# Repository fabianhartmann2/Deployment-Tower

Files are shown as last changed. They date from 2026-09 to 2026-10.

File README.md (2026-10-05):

# Integrated Deployment Station CAD

Parametric CadQuery concept for an FDM-printed station containing a Mac mini M4, a Teltonika RUTM30, and a Mean Well APV-35-36. The modeled default is a **165 x 165 x 280 mm fixed enclosure** (base, panels, and cap included; removable handle and antennas excluded), with a **1:1:1.697** width:depth:height ratio.

> **Prototype status and safety boundary:** this package is editable concept/prototype mechanical CAD. It is not a production release, an electrical design, a safe-working-load rating, or evidence of regulatory compliance. Computational PASS results prove only the checks named in the generated report. Actual hardware fit, cables and overmoulds, printing tolerances, thermal behavior, carrying load/cycles, and qualified 230 V electrical review and tests are still pending. Do not energize a built unit until a competent electrical designer has completed the architecture and a qualified person has inspected and tested the complete assembly.

## Architecture

The stack from bottom to top is:

1. a removable dark base with 5 mm feet, a 116 mm intake opening, and a continuous lower-rear Mac-button path;
2. a horizontal Mac mini on a physically calibrated Ø112 open-ring, three-pad cradle with 0.30 mm side clearance, four lowered positive-Z clip/cam retainers, and two bottom-operated release rails;
3. a shell-supported, separately covered APV/mains compartment, a distinct low-voltage/data lane, and a provisional reserved Mac-AC route;
4. a horizontal RUTM30 on four replaceable compliant support pads and a shell-supported removable tray at `Z=151`, retained at the rear corners by two adjustable M3-screwed stops rather than brittle flexure clips; and
5. a reinforced upper shell and laterally sliding cap with a removable handle fastened from the cap underside by four hidden M3 screws, broad feet, full-depth handle inserts, two selected dovetail rails, and shell-tied load paths.

The lower and upper shell modules fit the Bambu Lab X1 Carbon's 256 mm build cube. Their load-bearing split uses six hidden M4 joints, an internal U-shaped belt in each shell, and three locating keys; all screw heads, tool corridors, and insert openings remain inside the closed exterior skin. A physical v3 assembly found the original Ø7.6 head pockets tight for measured Ø7.0 heads, so the current source uses Ø8.2 pockets plus 8.4 mm internal-only entry slots. The formerly unsupported 4 mm rear sill is tied into the lower shell by an internal angle beam. The upper shell carries two recessed 70 x 70 mm logo panels using concealed 6 x 3 mm shell magnets opposed by 6 x 1.5 mm panel magnets. The former side antenna docks and their shell bosses are removed; four cellular and two Wi-Fi antennas now mount on six screw-clamped rear bulkheads. The C8 island and closed terminal tunnel move with the complete power compartment to +X; the full-height rear service panel removes around the island. Raised cable-tie bridges preserve a solid box floor, the two APV axes use top-service blind insert pilots, and four wall-tied bosses support the cover. These are mechanical provisions only and do not authorize wiring or energization.

The current joint labels deliberately distinguish **M3x14 base**, **M3x10 Mac-cradle**, hidden underside **M3x14 handle**, recessed low-head **M3x6 router-tray**, **M3x8 service/cover**, hidden **M4x10 cap locks**, and **M4x18 shell-seam** stacks. Physical coupons selected Ø4.2 M3 and Ø5.4 M4 insert pilots. The handle screws pass upward through the detached cap into the full 8 mm feet; the selected dovetails carry vertical cap load while two M4 locks prevent sideways motion. Exact screw heads, engagement, torque, pull-out, and final lengths remain provisional until joint-stack tests pass.

The official router geometry is imported from `reference/0112_RUTM30AMBKX_02.STEP`. The Mac, APV, antennas, C8, extensions, plugs, and cable paths are controlled placeholders; see [assumptions.md](reports/assumptions.md).

## Coordinate system

All dimensions are millimetres.

- Origin: centre of the external footprint on the desk-contact plane.
- +X: right when looking at the front.
- +Y: toward the rear service face.
- +Z: upward.
- Fixed body: approximately `X=-82.5..82.5`, `Y=-82.5..82.5`, `Z=0..280`.
- Equipment positions in `layout.py` are reference-envelope centres.

The principal centres are Mac `(0,-8,41)`, APV `(35,5,103.55)`, and RUTM30 `(0,28,170.5)`. The Mac reference preserves 50 mm overall height while representing the physically observed 8 mm underside drop below its retained square body. Full datums, packaging ranges, and parameter defaults are in [dimensions.md](reports/dimensions.md).

## Build, test, and export

Python 3.10-3.12 is supported; CadQuery is pinned to 2.6.1. From `cad/`:

```sh
python3 -m venv .venv
.venv/bin/python -m pip install --upgrade pip
.venv/bin/python -m pip install -e ".[test]"
.venv/bin/python -m pytest
.venv/bin/python -m deployment_station.export
```

On Windows, substitute `.venv\Scripts\python.exe` for `.venv/bin/python`. Installed console-script equivalents are `deployment-station-export`, `deployment-station-validate`, and the macOS-only `deployment-station-quicklook`.

The export command rebuilds all parts from `parameters.py`, writes STEP/STL and renders, reopens every STEP, validates every STL, writes the manifest and reports, and exits non-zero if any validation result is `FAIL`. A report-only rerun against the existing STL directory is:

```sh
.venv/bin/python -m deployment_station.validation
```

The complete export command is the authoritative check. The standalone report-only command reruns geometry and whole-file mesh checks; export additionally verifies the actual packed print orientation and independently checks every disconnected mesh component for grounding and manifold integrity.

The non-default proportional-scaling API intentionally raises `ValueError`. Absolute equipment, port, split, and load-path datums cannot be safely scaled as one ratio; a different enclosure width requires a coordinated repack and new verification.

## Computational-result authority

The source checks are fail-gated, but aggregate counts and artifact hashes are intentionally not frozen in this narrative before regeneration. Run the export command after every source change, then use [validation_results.md](reports/validation_results.md), `validation.json`, and `export_manifest.json` as the generated record for that exact build. The checks cover installed-part pairs, selected equipment/mount intersections, print-volume and solid validity, critical mating geometry, STEP reopen, and STL mesh integrity. A zero-FAIL report remains computational evidence only; every physical, thermal, load, signal, cable, and electrical item marked WARN or PENDING remains open.

## Generated outputs

The current source registry expects **18 printable definitions**: 14 installed assembly parts plus four reusable/non-installed templates. Regeneration writes:

- one printable-part STEP and one print-oriented STL for each registered definition;
- 21 coupon STEP files and 21 coupon STL files, including retained historical fit articles;
- `complete_assembly.step`, `exploded_assembly.step`, and `packaging_study.step`;
- `component_envelopes.step`, containing non-printable references and keep-outs;
- four deterministic PNG renders; and
- `reports/export_manifest.json`, with the authoritative regenerated paths, sizes, SHA-256 hashes, and design-space STEP bounding boxes.

STEP files remain in assembly coordinates. STL files receive the documented print-orientation transform and are placed on `Z=0`. No 3MF is generated because this export path cannot preserve dependable slicer/process settings.

### macOS Finder model

`exports/interactive/complete_assembly_finder.usdz` is a color, interactive Quick Look model containing all 14 installed printed parts plus equipment and interface-hardware references. Select it in Finder and press Space, or open it directly, to orbit, pan, and zoom. It uses metres-per-unit metadata corresponding to the millimetre CAD model and passes Apple's strict RealityKit USDZ validation.

On macOS with the Apple USD command-line tools available, regenerate it with:

```sh
.venv/bin/python -m deployment_station.quicklook
```

This convenience visualization is generated separately from the fail-gated STEP/STL manifest and is not a manufacturing export.

## Direct versus extended interfaces

| Interface | Decision | CAD implementation | Verification boundary |
| --- | --- | --- | --- |
| Four cellular SMA connections | Rear bulkhead extensions | Four of six Ø6.6 rear holes with thinned 2.0 mm clamping lands; row sequence Mobile / Wi-Fi / Mobile / Mobile / Wi-Fi / Mobile | Exact pigtails, nut torque, strain relief, first bends, and antenna load test pending |
| Two Wi-Fi RP-SMA connections | Rear bulkhead extensions | Two of the same six screw-clamped rear positions; former side docks removed | Exact RP-SMA gender, coax routing, antenna spacing, RF performance, and load test pending |
| External Ethernet | One replaceable extension | One accepted 17 x 14 opening with 27.6 mm mounting pitch directly in the rear panel | Exact screws/locking, latch access, bend space, strain support, and link performance pending |
| Internal Mac Ethernet | Internal patch lead | Placeholder plug volume in low-voltage lane | Consumes one native router port; actual lead fit pending |
| Mac HDMI | Replaceable extension | Accepted V7 mount relocated to `(-6,108)`—60 mm from the right and 90 mm from the bottom when viewed from behind—with a 13 mm shelf and two top-down blind M3 mounts | Cable bend, strain support, access, and functional test pending |
| Two Mac USB-C | Replaceable extensions | Accepted V7 mounts relocated to `(-24,68)` and `(-41,78)`—rear-view right/bottom offsets `(42,50)` and `(25,60)`—mounted from inside to 6 mm blind-boss bridges with sharp 14 x 6.5 x 2.5 mm reliefs | Cable bend, strain support, access, and functional test pending |
| Mac AC | Internal only | Diameter-12 gland and continuous stepped 6 mm reserved envelope from the covered zone toward the provisional Mac connector | This is packaging space, not a selected conduit or completed branch architecture; qualified design remains PENDING |
| Candidate measured C8 | Direct component | Accepted 21 x 12.5 opening on the fixed inlet island at `(38,116)` with two full-depth Ø4.2 M3 insert pockets, integral with the relocated closed compartment | Insert installation, shroud, wiring, and electrical review pending |
| Mac power button | Direct mechanical reach | Continuous rear-left/underside finger path; no Mac modification | Handedness corrected by full-cradle trial; physical ergonomics/guarding cycles pending |

The two native router ports now have a defined one-to-one allocation: one internal Mac link and one external Ethernet extension. No second external Ethernet opening is modeled.

## Source map

| Module | Responsibility |
| --- | --- |
| `parameters.py`, `layout.py` | Defaults, datums, and packaging locations |
| `components.py` | Official router import; controlled equipment, hardware, cable, and removal placeholders |
| `base.py`, `mac_mount.py` | Base, intake/button path, three 2 mm pad positions in 1 mm seats, four clip/cam retainers, two bottom release rails, and shell-fastened cradle ears |
| `shell.py` | Split shell, reinforced rear sill, three seam keys, six hidden internal seam joints/belts, magnetic logo receivers, dovetail cap rails, equipment supports, and handle load path |
| `router_tray.py`, `rear_panel.py` | Router support, physically corrected side/top fit, four compliant pads, adjustable screw-mounted rear stops, and a full-height one-piece rear panel with six direct RF bulkheads and the measured extension mounts |
| `power_compartment.py` | Mechanical APV/mains enclosure, fixed C8 island/tunnel, sealed-floor tie bridges, top-service APV pilots, wall-tied upper cover bosses, four verified shell-mount access corridors, exits, and cover |
| `handle.py` | Sliding dovetail cap, two concealed anti-slide locks, structural beams, underside four-screw handle feet, and mounting coupon |
| `wifi_dock.py`, `logo_panel.py` | Legacy dock coupon source retained for traceability; production magnet-retained logo panels |
| `coupons.py` | High-risk physical-fit articles, including the original calibration set and four measured v4 interface coupons |
| `prototype_v4.py` | Coupon-stage measured Ethernet/HDMI/USB-C/C8 interfaces, RF bulkhead wall trials, blind logo magnets, and concealed cap dovetails for the pending v4 redesign |
| `assembly.py`, `render.py` | Part registry, assemblies, non-printable references, and views |
| `validation.py`, `export.py` | Fail-closed computational checks and reproducible outputs |

## Documentation

- [dimensions.md](reports/dimensions.md) — envelope, packaging, part envelopes, and parameter reference.
- [interface_decisions.md](reports/interface_decisions.md) — direct/extension decisions and the one-internal/one-external Ethernet allocation.
- [bom.md](reports/bom.md) — printed parts, equipment, provisional hardware, screws, and inserts.
- [assembly.md](reports/assembly.md) — de-energized assembly, service, and load-path sequence.
- [print_plan.md](reports/print_plan.md) — orientations, starting process, and coupon order.
- [assumptions.md](reports/assumptions.md) — evidence hierarchy, unresolved measurements, and deviations.
- [requirements_traceability.md](reports/requirements_traceability.md) — handoff IDs mapped to modules, tests, and closure evidence.
- [known_limitations.md](reports/known_limitations.md) — release blockers and explicit electrical boundary.
- [validation_results.md](reports/validation_results.md) — generated computational record.
- [coupon_results_2026-09-10.md](reports/coupon_results_2026-09-10.md) — physical coupon observations, revisions, and selected v2 fits.

## Release boundary

The repository demonstrates a coherent, printable mechanical prototype concept. Before a complete prototype is frozen, it still requires the actual devices, extensions, cables, inserts, pads, and connector hardware to be measured and dry-fitted and physical coupons and service trials to pass. The Mac-AC envelope is only a reserved path, and the branch hardware/topology, APV lead bends, protective separation, restraint, and materials are not released. Before carrying or energizing, it additionally requires load/cycle and thermal tests, a complete competent electrical design, and qualified inspection/testing. Supplier availability and lifecycle status—including the specified C8 inlet—must be reconfirmed before procurement.

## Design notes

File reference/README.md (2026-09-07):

# External CAD reference

`0112_RUTM30AMBKX_02.STEP` is the native AP214 model supplied by Teltonika in
the official RUTM30 spatial-measurement archive:

https://wiki.teltonika-networks.com/images/d/d4/Networking_rutm30_manual_spatial_measurements_3d.zip

The archive was retrieved on 2026-09-07.  The model identifies itself as a
SolidWorks 2024 export and contains 37 solids.  Its measured bounding box is
100.0000 x 30.0000 x 93.6999 mm in supplier X/Y/Z axes, matching the published
100 x 30 x 93.7 mm housing dimensions.  `components.py` rotates it into station
X=width, Y=depth, Z=height coordinates and retains it as non-printable reference
geometry.

No official STEP was supplied for the Mac mini, APV-35-36, antennas, or cable
overmoulds.  Their controlled envelopes and uncertainty are documented in
`reports/assumptions.md`.

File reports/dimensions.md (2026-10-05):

# Dimensions and parameter reference

All dimensions are millimetres unless stated otherwise. `src/deployment_station/parameters.py` is the executable source of truth; this report records its current `DEFAULT` configuration. After regeneration, exact exported hashes and design-space bounding boxes are in `export_manifest.json`; do not use a pre-regeneration manifest for the current source.

## Coordinate system and datums

- Origin: centre of the enclosure footprint at the desk-contact plane.
- +X: right when looking at the front.
- +Y: toward the rear/service face.
- +Z: upward.
- Centre planes: `X=0`, `Y=0`; desk plane: `Z=0`.
- Front/rear exterior planes: `Y=-82.5` / `Y=+82.5`.
- Fixed-body top: `Z=280`.
- Equipment locations are reference-envelope centres, not guaranteed physical datums.

## Selected exterior and print package

| Item | Default | Boundary |
| --- | ---: | --- |
| Fixed enclosure | 165 x 165 x 280 | Base, shells, cap, and panels included; removable handle and antennas excluded |
| Width:depth:height | 1:1:1.69697 | Target 1:1:1.70; absolute height-ratio error 0.00303 |
| Main radii | 24 outer / 20.8 inner | Rounded-square shell |
| Main / minimum named wall | 3.2 / 2.4 | Minimum check covers controlled wall parameters, not every local tessellated section |
| Desk air gap | 5 | Nominal printed-foot height; pad compression is not included |
| Installed handle range | `Z=280..360` | Ergonomic handle design bbox is 80 high and is excluded from fixed envelope |
| Printer build cube | 256 x 256 x 256 | Every individual printable bbox fits after permitted orientation; slicer confirmation remains required |

The generated fixed-envelope result is `165.00 x 165.00 x 280.00`. Non-default proportional scaling is intentionally rejected: changing width requires a coordinated repack of absolute hardware, interface, seam, and load-path datums.

## Packaging centres and ranges

| Item | Centre `(X,Y,Z)` / datum | Controlled envelope | Approximate range |
| --- | ---: | ---: | --- |
| Mac mini placeholder | `(0,-8,41)` | 127 x 127 x 50 overall | X `-63.5..63.5`; Y `-71.5..55.5`; Z `16..66`; 42 mm retained square body above support plane plus 8 mm central underside drop |
| Mac support plane | `Z=24` | — | 10 above nominal base top `Z=14` |
| APV case placeholder | `(35,8,103.55)` | 57 X x 84 Y x 29.5 Z | Relocated with the complete power assembly to +X so the Mac-determined low-voltage cables remain on the opposite side |
| APV/mains box | centre `(35,5,105)` | nominal 72 x 120 x 44 | X `-1..71`, Y `-55..65`; the box, C8 island/tunnel, cover, mounts, exits, and mains envelopes move as one assembly |
| Low-voltage lane | `(-48,0,116)` | 34 x 122 x 76 | X `-65..-31`; Y `-61..61`; Z `78..154` |
| Mac-AC reserved corridor | gland datum `(55,-33.5,83)` toward provisional Mac AC | stepped 6 wide packaging solid | Mirrored side run remains a reserved envelope only; no physical conduit or electrical release implied |
| Router tray datum | `Z=151` | 3 thick plate | Shell-supported fasteners; guide/retainer geometry extends above the plate |
| RUTM30 official STEP | `(0,28,170.5)` | 100 x 93.7 x 30 | X `-50..50`; Y `-18.85..74.85`; Z `155.5..185.5` |
| Handle anchor reference | `Z=260` | centres at X `+/-54`, Y `-42` | Cap lock geometry near fixed-body top |

The Mac, APV, antennas, C8, extensions, plugs, and cable ranges are controlled placeholders. Only the RUTM30 body is imported from official STEP.

## Shell, panels, and interfaces

| Feature | Current default |
| --- | ---: |
| Base | 14 high total; 5 high feet; visible skin inset 1.5 per side |
| Shell split | lower nominal top `Z=105`; 0.8 shadow gap; upper shell to `Z=268` |
| Structural shell seam | Six hidden vertical M4 axes: X `±76.8`, Y `-50/10/50`; Ø10.4 local bosses/lugs, Ø8.2 x 3.2 internal low-head pockets for measured Ø7.0 heads, 8.4-wide internal entry slots, Ø5.5 top-driver corridors; no exterior openings |
| Rear lower sill | Existing 4 mm sill reinforced internally by a 145 x 11 x 4 flange and 145 x 4 x 10 web; rear-panel seat and Mac-button path recut clear |
| Cap | `Z=268..280`, 12 high; two transverse dovetail grooves and two blind M4 lock inserts |
| Rear shell opening | 120 wide, `Z=18..268` |
| Rear service panel | 132 x 250 x 3.2; radius 8; eight M3 positions |
| Rear SMA row | six direct Ø6.6 holes at X `-50,-30,-10,10,30,50`, Z `158`; inner Ø12 rebates leave 2.0 mm exterior lands |
| RF bulkhead row | Six Ø6.6 holes at 20 pitch, centre `Z=158`; 2.0 mm outer clamping lands; Mobile/Wi-Fi/Mobile/Mobile/Wi-Fi/Mobile |
| External Ethernet opening | 17 x 14; centre `(X,Z)=(-42,108)`, or 24 mm from the visible right edge and 90 mm from the bottom when viewed from behind; 27.6 mm horizontal M3 pitch with accepted 1 mm vertical correction |
| External Ethernet inner service envelope | 22 x 23 x 42 adapter body; 18 mm angled plug; 6 mm cable with a reserved 20 mm bend toward the -X low-voltage lane |
| C8 fixed island | 42 x 28 nominal island; inlet centre `(X,Z)=(38,116)` on relocated +X power compartment |
| C8 controlled cutout | 21 x 12.5 plus 0.40 profile allowance; two full-depth Ø4.2 M3 insert pockets at 30 pitch |
| HDMI extension opening | 16.4 x 6.4; centre `(X,Z)=(-6,108)`; equivalently 60 mm from the visible right edge and 90 mm from the bottom when viewed from behind; 13 mm shelf; two top-down blind M3 axes |
| USB-C extension openings | 10.4 x 4.4; centres `(X,Z)=(-24,68),(-41,78)`; equivalently rear-view right/bottom offsets `(42,50)` and `(25,60)`; 6 mm rear boss bridges and sharp 14 x 6.5 x 2.5 pockets |
| Mac button approach | 26 wide; installed base run follows the button-to-rear distance (42.5 before the rounded end); continuous swept path validated with diameter-11 probe |
| Base intake opening | diameter 116 at Mac Y centre |
| Logo faces | 70 x 70 x 2.4, radius 6, centre `Z=156`, 0.8 reveal; two blind Ø6.2 x 1.7 panel pockets and two Ø6.2 x 3.2 shell pockets per side |

`finger_well_reach=38` controls the isolated button coupon. The installed base and cradle derive their longer clearances from the provisional button and rear-face coordinates.

## Exported printable-part bounding boxes

These are assembly-coordinate STEP bounding boxes. Hooks, bosses, clips, and retainers can make them larger than their nominal face/plate values.

| Part | Design bbox X x Y x Z |
| --- | ---: |
| `base` | 162 x 162 x 14 |
| `mac_cradle` | 152 x 137 x 51.2, including four lowered Z-retention clips and two extended release rails |
| `lower_shell` | 165 x 165 x 97 |
| `upper_shell` | 165 x 164.9531 x 162.6 |
| `router_tray` | approximately 120 x 98.9 x 37.5, including the two rear insert towers |
| each `router_rear_retainer_*` | approximately 15 x 8.7 x 10.5; separate slotted rear corner stop |
| `power_compartment` | 72 x 134.5 x 44 |
| `power_compartment_cover` | 72 x 120 x 4.8 |
| `rear_panel` | 132 x 16.2 x 250, including internal HDMI/USB supports |
| `upper_cap` | 165 x 165 x 12 |
| `removable_handle` | 150 x 32 x 80 |
| each installed/blank logo panel | 2.4 x 70 x 70 |
| example embossed logo panel | 3.2 x 70 x 70 |
| Mac compliant-pad template | 14.6 x 14.6 x 2 |
| router compliant-pad template | 8 x 16 x 1.3 |

## Exported coupon bounding boxes

| Coupon | Design bbox X x Y x Z |
| --- | ---: |
| `coupon_c8_cutout` | 55 x 3.2 x 35 |
| `coupon_insert_boss` | 46 x 28 x 14 |
| `coupon_m4_seam_insert` | 54 x 24 x 16; three vertical Ø5.4/5.6/5.8 pilot bosses |
| `coupon_rear_panel_fit_v2` | 120 x 22.5 x 37; upright receiver plus flat insert |
| `coupon_logo_mount` | 23.2 x 32 x 18 |
| `coupon_handle_mount` | 100 x 36 x 12 |
| `coupon_wifi_dock_v2` | 17.9 x 120 x 42 |
| `coupon_mac_button_recess` | 54 x 58 x 12 |
| `coupon_router_rf_access` | 110 x 3.2 x 46 |
| `coupon_rear_io_v1` | 180 x 3.2 x 45; Ethernet/HDMI/USB-C/candidate-C8 strip |
| `coupon_rear_io_mount_v2` | 180 x 31.2 x 50; corrected Ethernet/C8 plus inside USB bosses and top-down HDMI shelf |
| `coupon_rear_io_mount_v3` | 180 x 31.2 x 50; v2 mounting layout with M3 rather than M4 HDMI insert pilots |
| `coupon_rear_io_mount_v4` | 180 x 31.2 x 50; HDMI shelf -1 mm/axes 9 mm, USB 6 mm bosses and inside 12.4 x 5.4 x 2.2 reinforcement rebate |
| `coupon_rear_io_mount_v5` | 180 x 31.2 x 50; v4 HDMI plus 28 x 12 x 6 USB boss bridge with PCB-facing 12.4 x 5.4 x 2.2 stepped pocket |
| `coupon_rear_io_mount_v6` | 180 x 16.2 x 50; accepted HDMI position with 13 mm shelf depth, USB boss bridge with PCB-facing 13 x 6 x 2.2 stepped pocket |
| `coupon_rear_io_mount_v7` | 180 x 16.2 x 50; v6 HDMI geometry with a sharp-cornered PCB-facing 14 x 6.5 x 2.5 USB pocket |
| `coupon_rf_bulkhead_v1` | 78 x 3.2 x 50; six RF trials at two local wall thicknesses |
| `coupon_logo_magnet_v1` | 16.4 x 110 x 35 design compound; separate blind-pocket receiver and steel-recess panel |
| `coupon_logo_magnet_v2` | 16.4 x 110 x 35 design compound; 3 mm shell magnets opposed by 1.5 mm panel magnets |
| `coupon_cap_dovetail_v1` | 56 x 18 x 11 design compound; six separately packed rail/slider bodies |
| `coupon_cap_dovetail_v2` | 56 x 18 x 11 design compound; 0.05/0.10/0.15 mm-per-side rail/slider pairs |

### Pending v4 measured-interface coupon parameters

| Parameter group | Defaults | Meaning |
| --- | --- | --- |
| Ethernet opening / pitch / inner body | 17 x 14 / 27.6 / 22 x 23 x 42 | Owner-measured downward-cable adapter; coupon adds 0.20 mm per cutout side and 0.20 mm diametral hole allowance |
| HDMI opening / pitch / inner body / bend space | 16 x 6 / 27 / 19 x 13 x 13 / 45 | A6-A8T owner measurement; final inner support awaits coupon result |
| USB-C opening / shell rebate / oval pitch | 10 x 4 / 12 x 5 x 1.75 / 19 | T9B-T8T-NC 20P; two identical production interfaces intended |
| Candidate C8 opening / pitch / first envelope | 21 x 12.5 / 29 / 35.5 x 15.1 x 3 | Mechanical coupon only; no mains approval implied |
| RF bulkhead trials | diameter 6.6/6.8/7.0; wall 3.2/2.0 | Select actual SMA-mobile and RP-SMA-Wi-Fi fit/thread stack physically |
| Logo magnet pocket / skins | shell Ø6.2 x 3.2 behind 0.6; panel Ø6.2 x 1.7 leaving about 0.7 | Both magnet pockets fit; pull-off, rattle, bonding, and cycle checks remain; recessed panel positions itself; no finger notch |
| Cap dovetail clearance | v1 0.25/0.35/0.45; v2 0.05/0.10/0.15 per side; **selected 0.10 per side** | Two-notch pair selected; 0.05 rejected as too tight for the longer production rail; final positive lock and load path not yet modeled |
| DC/DC reserved envelope | 71 x 36 x 25 | 24 V/1 A owner-supplied module; mount, terminals, thermal and electrical role unresolved |

## Parameter reference

### Enclosure and fit

| Parameter group | Defaults | Meaning |
| --- | --- | --- |
| `width`, `depth`, `height` | 165, 165, 280 | Fixed exterior |
| `target_height_ratio` | 1.70 | Height/width target |
| `wall`, `minimum_wall` | 3.2, 2.4 | Named shell/wall controls |
| `outer_corner_radius`, `inner_corner_radius` | 24, 20.8 | Main radii |
| `base_height`, `foot_height`, `cap_height` | 14, 5, 12 | Vertical modules |
| `lower_shell_top`, `shell_top`, `shadow_gap` | 105, 268, 0.8 | Split/cap datums |
| Seam axes / boss / lug | X ±76.8; Y -50/10/50; Ø10.4; 11 high | Six hidden internal M4 joints distributed along the side walls |
| Seam head / pocket / entry / driver | measured Ø7.0 / Ø8.2 x 3.2 / 8.4 wide / Ø5.5 | 0.6 radial head relief plus explicit lateral insertion and top tool access; 1.6 mm local closed exterior skin remains behind the pocket |
| `rear_opening_width`, `rear_opening_bottom/top` | 120, 18/252 | Shell service opening |
| `rear_panel_width/height/thickness/radius` | 132/236/3.2/8 | Rear service panel |
| `equipment_clearance` | 1.5 | Nominal equipment gap |
| `sliding_fit_per_side` | 0.30 | General sliding/seam-key fit |
| `service_panel_per_side` | 0.35 | Power-cover internal relief; independent of calibrated rear-panel seat |
| `rear_panel_x_per_side`, `rear_panel_z_per_side` | 0.15, 0.05 | Calibrated rear-panel seat allowances; v2 physical fit reported passed |
| `logo_panel_per_side` | 0.25 | Logo receiver clearance |
| `wifi_clip_radial` | 0.50 | Antenna capture allowance selected by the three-marker physical coupon |
| `snap_feature_per_side`, `insert_pilot_allowance` | 0.20, -0.15 | Reserved references; actual mechanisms/coupon variants have explicit geometry |

### Equipment and cable references

| Parameter group | Defaults | Meaning / evidence boundary |
| --- | --- | --- |
| Mac `width/depth/height/radius/mass` | 127/127/50/12; 0.67 kg | Controlled placeholder |
| Mac `support_plane_z`, `center_y`, underside drop/retained-body height | 24, -8, 8/42 | Placement revised from the full-cradle physical trial while preserving 50 mm overall height |
| Mac button side/edge offsets/diameter/free gap | rear-left; 13.5/13.5/11/0.75 | Handedness physically corrected; exact centre remains photo-derived |
| Mac intake inner/outer diameters | 100/112 | Photo-derived exclusion annulus |
| Mac cradle side clearance / central opening | 0.30 per side / diameter 112 | Selected from the first full-cradle physical trial; opening reduced 4 mm |
| Mac plug depth/clearance height | 34/24 | Provisional volumes |
| Mac base pad seat/pad thickness | 1 / 2 | Three active seats; actual pad compression/contact pending |
| Mac Z-retention stations | Y offsets -17/+17 on both X sides | Four clip/cams lowered 8 mm to the 42 mm retained body; 1.2 nominal top gap; two linked bottom-release rails with 7.5 mm outreach |
| Router `width/depth/height/mass` | 100/93.7/30; 0.319 kg | Official body envelope / published mass |
| Router centre X/Y and tray Z | 0/28; 151 | Rear-biased packaging |
| RF connector depth/pitch/access diameter | 36/14.8/14 | Official centres; provisional connected access volume |
| RJ45 clearance W/H/depth | 18/16/40 | Provisional extension/plug volume |
| Router support pad W/D/T/compression | 8/16/1.3/0.4 | Four provisional compliant pads/lands; underside and preload unverified |
| Router physical fit corrections | side guides inward 1.0; top ledges down 0.6 | Responds to measured 1.3 mm side play per side and 1.0 mm top play; predicts about 0.3 mm physical side clearance |
| Router rear stops | two separate 4 mm-thick corner stops; ±1.0 adjustment | Screw-retained after router insertion; rear contact datum corrected about 4.2 mm forward from the broken flexure centre while preserving 0.3 mm clearance to the official chassis |
| APV case L/W/H | 84/57/29.5 | Datasheet placeholder |
| APV longitudinal mounting delta / fixing hole | 98.6 / diameter 3.6 | Supplier drawing coordinates; actual unit check required |
| APV leads | 150 +/-10 long; 3.5 controlled diameter | Datasheet length; simplified clearance solids |
| Cable/coax minimum bend radius | 18 / provisional 20 | Recorded assumptions only; builders do not create tolerance-complete swept cables |

### Power compartment

| Parameter group | Defaults | Meaning |
| --- | --- | --- |
| Outer W/D/H | 72/120/44 | Nominal closed box; rear island/tunnel adds depth to bbox |
| Wall/bottom/cover | 2.4/2.8/2.8 | Mechanical containment geometry only |
| Centre X/Y; bottom Z | 35/8; 83 | Relocated +X placement |
| DC grommet / Mac AC gland openings | diameter 9 / 12 | Hardware selection pending |
| Mac AC gland datum / reserved route | X 55, Y -33.5 / 6 wide stepped solid | Packaging reservation only; no selected conduit, branch hardware, protection, or electrical acceptance |
| Raised tie bridges | 14 x 7 x 5 outer; 8 x 3 strap tunnel | Two internal bridges over continuous nominal floor; physical restraint/electrical suitability pending |
| APV blind mounting pilots | 2 axes; diameter 4.2 x 3 deep | Aligned to supplier diameter-3.6 lug axes; 2.7 residual sealed floor; exact insert/fastener pending |
| Cover bosses / screw | 4 wall-tied upper bosses, 12.0 high; M3x8 provisional | Diameter-4.2 x 5.5 pilots; 5.2 nominal engagement through 2.8 cover |
| Lower-shell mounting access | 4 floor bores at the unchanged lower-shell axes | Diameter-3.4 through bores; diameter-6.2 screw-head and diameter-4.5 driver corridors verified open |
| `mains_keepout_extra` | 4 | Packaging keep-out expansion, not an electrical clearance |

### Handle, cap, antennas, and logo panels

| Parameter group | Defaults | Meaning |
| --- | --- | --- |
| Handle grip | 130 span x Ø22 | Continuous cylinder with spherical shoulders; no hard grip/end corners |
| Rise; leg/root radii | 58; 12/16 | Round legs and flared load-spreading roots |
| Anchor spacing | 108 | Leg/foot centres at X `+/-54` |
| Foot W/D/T | 42/32/8 | Broad cap bearing area; four M3 insert pockets open from the hidden underside |
| Fastener offset | `+/-14` from each anchor | Four M3 axes at X `-68,-40,+40,+68`, Y `-42` |
| Rib thickness | 5 | Structural geometry |
| Complete mass / proof-load factor | 1.8 kg provisional / 4.0 | 70.6 N provisional test target; not a rating |
| Cap dovetails | two rails at Y `±68`; 0.10 mm clearance per side | Physical v2 coupon selection; cap slides laterally |
| Cap locks | two M4x10 axes at X `±55`, Y `0` | Blind cap inserts and internal shell clearances; prevents sideways escape |
| Rear antenna bulkheads | six Ø6.6 holes, 20 pitch, 2.0 clamping land | Four SMA mobile plus two RP-SMA Wi-Fi positions |
| Wi-Fi antenna length | 170 | Type-15 screw-on antenna reference; hinge sweep and RF validation pending |
| Logo size/thickness/radius | 70/2.4/6 | Face geometry |
| Logo pocket depth/reveal/emboss | 1.6/0.8/0.8 | Appearance parameters |
| Logo centre Z / removal | 156 / straight magnetic pull-off | Recess provides location; no finger notch |
| Logo magnets | shell 6 x 3; panel 6 x 1.5; pockets Ø6.2 | Two pairs per panel at Y `±25`; polarity/adhesive/pull force pending |

### Fasteners, inserts, and print

| Parameter group | Defaults | Meaning |
| --- | --- | --- |
| M3 screw stacks | M3x14 base/handle; M3x10 cradle; low-head M3x6 router tray; M3x8 router stops/service/cover | Separate lengths prevent marginal engagement or blind-pilot bottoming; all provisional pending joint tests |
| M4 screw stacks | M4x10 cap locks; M4x18 shell seam | Selected cap/seam geometry; provisional pending joint tests |
| M3/M4 clearance holes | diameter 3.4 / 4.5 | Modeled clearances |
| M3/M4 insert pilots | diameter 4.2 / 5.4 | Physically selected heat-set holes; M4 one-notch vertical coupon reported best fit |
| M3/M4 bosses | diameter 9 / 12 general; seam M4 diameter 10.4 | Modeled support values; seam rings are integrated into paired U-belts |
| Insert depth | 5.5 | Provisional; supplier and coupon govern |
| Low-head M3 recess | diameter 6.2 x 2.2 deep | Four router-tray positions; leaves 0.8 mm floor and about 0.7 mm under-router clearance for the measured 3.0 mm-high heads |
| Printer build X/Y/Z | 256/256/256 | Bounding-cube check |
| Nozzle / line width / layer | 0.4/0.45/0.20 | Starting process |
| Body wall lines / prototype material | 7 / ASA | Starting point only; thermal/electrical review governs final materials |

The parameter file centralizes intended design inputs, but a field can be a reserved design value or placeholder. Only geometry actually consumed by builders and the exact validations reported in [validation_results.md](validation_results.md) should be treated as computationally checked.

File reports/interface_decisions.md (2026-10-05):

# External-interface decisions

The handoff prefers direct native access when the device orientation, hand clearance, and cable path permit it. It permits a replaceable, mechanically supported extension when direct access produces poor routing, an impractical opening, or insufficient plug access. The decisions below apply to the fixed 165 mm package and remain subject to physical hardware tests.

## Direct versus extension table

| Required interface | Qty | Decision | Current CAD implementation | Rationale | Required physical closure |
| --- | ---: | --- | --- | --- | --- |
| Cellular RF | 4 | **Rear SMA bulkhead extensions** | Four Ø6.6 positions in a six-port rear row with 2.0 mm clamping lands | Allows standard screw-on enclosure antennas while short pigtails connect to the four native Mobile ports | Select exact SMA pigtails/bulkheads; verify gender, torque, strain relief, bends, antenna load, spacing, and RF performance |
| Wi-Fi RF | 2 | **Rear RP-SMA bulkhead extensions** | Two Ø6.6 positions in the same row accept the Type-15 screw-on antennas; side docks are removed | Avoids the failed/obsolete body-dock concept and provides standard external antenna mounting | Verify exact RP-SMA gender, pigtails, hinge clearance, torque, spacing, handling load, and RF performance |
| External Ethernet from RUTM30 | 1 | **Replaceable rear extension** | One accepted 17 x 14 opening at `(-42,108)` with 27.6 mm two-hole pitch and corrected vertical hole offset, directly in the rear panel | Stacks above the rear-view right USB-C and reserves its 42 mm inner body, 18 mm angled plug, and 20 mm bend in the -X low-voltage lane, away from the +X power box; the other native router port serves the internal Mac | Verify the measured adapter, latch access, cable bend, insertion load, link rate, screws, and replacement |
| Internal Mac-to-router Ethernet | 1 | **Internal patch lead** | Provisional 20 x 34 x 24 plug/service envelope in the low-voltage lane | Uses the router's second native Ethernet port | Select actual lead and verify bend/service path and link performance |
| Mac HDMI | 1 | **Replaceable rear extension on horizontal internal shelf** | V7 geometry is transferred into the full rear panel: 13 mm shelf, top-down M3 mounts, axes 9 mm behind the connector datum | The HDMI lead route is fixed by the Mac mini; the power compartment moved instead | Verify strain support, 45 mm bend/service loop, tool access, Mac removal, and function |
| Mac USB-C | 2 | **Replaceable rear extensions mounted behind rear panel** | V7 geometry is transferred twice: 6 mm boss bridges, inside screws, and sharp 14 x 6.5 x 2.5 mm reinforcement pockets; no exterior screw heads | Both fixed Mac cable routes stay in the low-voltage side while the power compartment moves to +X | Verify ribbon exits, strain support, removal access, Mac removal, and end-to-end operation |
| Mac AC | 1 | **Internal only** | Provisional plug clearance, relocated diameter-12 floor gland at `(X,Y)=(55,-33.5)`, and a continuous stepped 6 mm reserved envelope toward the Mac connector | `MAC-14` prohibits a dedicated external Mac-power opening; the reservation demonstrates only one collision-free packaging route | Complete single-inlet topology, branch/protection hardware, conduit/barrier, conductor restraint, materials, and qualified electrical proof remain PENDING |
| Candidate measured C8 inlet | 1 | **Direct mounted component** | V7 21 x 12.5 opening is transferred to the island at `(38,116)` on the relocated +X compartment; two Ø4.2 full-depth pockets accept M3 heat-set inserts and the island/tunnel remains covered when the rear panel is removed | Raising the inlet 8 mm and moving the box 3 mm forward clears the user-positioned HDMI shelf while retaining the mains service boundary | Reprint and revalidate insert installation and assembled access, then complete terminal shroud, strain relief, touch-safety, material, thermal, and qualified electrical validation; coupon fit is not electrical approval |
| Mac native power button | 1 | **Direct mechanical reach** | Continuous 26 mm-wide lower-rear/underside path; no electrical modification | Concealed native access with desk guarding | Measure actual button/intake/feet; test reach, 20 operations, accidental actuation, and comfort |
| Wi-Fi antenna mounting | 2 | **Screw-on rear bulkheads** | Type-15 antennas attach directly to the two RP-SMA bulkheads; no side body docks remain | Standardized removable mounting with no separate printed flexure | Verify tightening, hinge sweep, spacing, carry/shake load, bulkhead anti-rotation, cable strain relief, and 20 cycles |
| PR1KC540 body transport | 0 | **Intentionally omitted** | No body dock | `NET-10` explicitly prohibits an enclosure-mounted dock | Inspection; connected leads still need edge protection and support |

An opening, two-hole M3 pattern, or reference body is not a released extension mount. Exact extension part numbers, vendor hole patterns, anti-rotation features, fasteners, and internal cable terminations remain subject to the physical parts.

## Router connector row and rear bulkheads

The official service-face sequence is:

`Mobile 1 — Wi-Fi 1 — Mobile 2 — Mobile 3 — Wi-Fi 2 — Mobile 4`

The native router centres remain at 14.8 mm pitch, but the rear bulkheads are redistributed to 20 mm pitch at `Z=158` for washer/nut and antenna clearance. The sequence is preserved through six short internal pigtails. Every rear hole is Ø6.6 and the inner rebate leaves a 2.0 mm exterior clamping land.

The generated check proves six open axes, 20 mm pitch, and surrounding clamping material. It does not prove connector gender, nut torque, anti-rotation, coax routing, strain relief, antenna loads, spacing, detuning, or RF performance. The selected Ø6.6/2.0 coupon geometry must be repeated if hardware or print process changes.

The router is installed through the rear opening from +Y toward the front (-Y), where the front stop arrests travel. The original printed rear flexures broke and sat about 5 mm behind the physical chassis, so they are withdrawn. Two rigid slotted corner stops are fitted afterward and secured to tray insert towers with M3x8 screws. Service removal is the reverse motion along +Y after both stops are unscrewed. Direction and removal remain subject to a fully wired physical trial.

## Ethernet allocation

The owner selected exactly one external Ethernet connection. The two native RUTM30 ports are therefore allocated one-to-one: one internal Mac-to-router patch lead and one rear-panel Ethernet extension. The former two-port bezel and its second external Ethernet opening are removed, so no active switch or three-link topology is assumed by the CAD. Actual cable routing, link performance, strain support, and latch/service access remain physical checks.

## Fixed C8 service boundary

The inlet is not mounted to the routine rear service panel. `power_compartment.py` creates the inlet island and a closed tunnel back to the separately covered power box; `rear_panel.py` removes a clearance island around that fixed structure. Removing the eight rear-panel screws therefore leaves the inlet and its mechanical terminal boundary in place. The compartment also has two raised tie bridges over a continuous nominal floor, two blind top-service APV insert pilots, four wall-tied upper cover bosses, and four unobstructed lower-shell fastening corridors.

This is a mechanical service concept only. The stepped Mac-AC solid is a reserved envelope rather than a selected protective conduit. None of these features establishes touch safety, required clearances, insulating properties, terminal coverage, branch topology, conductor restraint, protection, temperature rating, or regulatory compliance. Rear-panel service is de-energized work, opening the inner power cover is a separate qualified operation, and no built unit may be energized before competent architecture and qualified inspection/tests are complete.

## Interfaces intentionally not exposed

No dedicated external openings are modeled for router LEDs, SIM slots, reset, USB, GNSS, other Mac ports, the headphone jack, Mac status LED, an external power switch, or an externally accessible fuse holder. The high rear slots are general enclosure exhaust openings, not device-interface access.

## Extension acceptance criteria

Before an HDMI, USB-C, or Ethernet extension is accepted, record its exact manufacturer and part number and verify that it:

- supports the required signal/performance mode end to end;
- has positive, replaceable panel retention and anti-rotation where needed;
- replaces or explicitly approves the provisional two-hole M3 flange datums against the vendor drawing and real part;
- does not transfer plug forces to a native device port;
- allows full insertion and latch/release operation with the intended cable overmould;
- fits its internal lead, bend radius, and service loop without pinching or blocking removal;
- survives the defined service cycles; and
- remains outside the mains boundary and Mac intake/button/removal paths.

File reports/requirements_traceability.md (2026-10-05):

# Requirements traceability

`Implemented` means the named geometry or intentional omission exists. It does not mean a handoff requirement with physical, thermal, load, electrical, or owner-review acceptance criteria is closed.

| Handoff ID(s) | Principal implementation | Computational evidence | State / required closure |
| --- | --- | --- | --- |
| `ENV-01`-`ENV-03` | `parameters.py`, `base.py`, `shell.py`, `handle.py`; fixed 165 x 165 x 280 body | `test_default_envelope_and_ratio`; square/proportion/fixed-envelope checks; `test_partial_proportional_scaling_is_rejected` | Default is 1:1:1.697. Other widths deliberately rejected pending coordinated repack and revalidation. |
| `ENV-04`-`ENV-06`, `ENV-09` | Rounded white shell, dark recessed base/rear, shadow seam, concentrated rear openings; `render.py` | Four deterministic renders; exterior bbox checks | Owner industrial-design, label, and printed-finish review pending. |
| `ENV-07`, `ENV-08`, `HDL-01`-`HDL-08` | `handle.py` four hidden underside M3x14 axes, 8 mm feet, cap bearing pads, selected dual dovetails and two concealed M4x10 locks; `shell.py` crossbars, paired U-belts, and six hidden M4 seam joints | Connected-solid, all-pairs zero-interference, handle-axis/insert/bearing witnesses, dovetail engagement, hidden-lock and six-axis seam checks, length stacks, and coupons | Mating/load-path geometry implemented; Ø5.4 M4 and 0.10 mm/side dovetail coupons selected. Insert pull-out/torque, full-length sliding, material/layers, measured mass, creep, and controlled 4x proof-load tests pending. |
| `ENV-10` | Scope in README/limitations | Documentation inspection | Dry indoor/careful transport only; no ingress/drop claim. |
| `LOGO-01`-`LOGO-06`, `LOGO-09` | `logo_panel.py`: two recessed 70 mm panels and blank/embossed templates; `shell.py` has two blind 6 x 3 mm magnet receivers per side | Required-part, validity/build, square-face, blind-pocket/receiver witnesses, connected-solid, and pairwise checks | Implemented geometry; appearance, adhesive, polarity, pull-off force, rattle, and service motion pending. |
| `LOGO-07`, `LOGO-08`, `OPEN-18` | Two 6 x 1.5 mm panel magnets oppose two 6 x 3 mm shell magnets; recess provides position; no screw or finger notch | V2 magnet coupon result, pocket/skin checks, and no installed interference | Adhesive qualification, 20-cycle, rattle/carry, sharp-edge, stiffness, and owner-appearance tests pending. |
| `MAC-01` | `layout.py`, `components.py`, `mac_mount.py`; overall-envelope centre `(0,-8,41)` | Mac-versus-shell and Mac-versus-cradle intersection checks | Horizontal bottom placement preserves the official 127 x 127 x 50 envelope while representing the physically observed 8 mm underside drop. |
| `MAC-02`, `MAC-03`, `MEC-05` | Three 1 mm recessed seats for 2 mm base pads, 0.30 mm side/front/rear keepers, four 8 mm-lowered positive-Z clip/cams with wear-pad pockets, two extended linked bottom release rails, pad template | Intake exclusion; mount interference; clip overhang/gap/cam/release geometry; validity/connectivity/pairwise checks | First full-cradle trial identified and drove the dimensional revision. Reprint contact map, pad compression, insertion/release force, retention, shake, cycle, and scratch tests remain pending. |
| `MAC-04`, `SVC-01` | Four downward-accessible M3x10 cradle screws, removable M3x14 four-screw base, two bottom release rails | Required-part/pairwise/button-path/Mac-retention checks and sampled Mac-plus-cradle downward service sweep | Fully wired physical clip release and downward-removal trial pending. |
| `MAC-05`-`MAC-10`, `OPEN-04` | Physically corrected rear-left button reference; continuous base/cradle/lower-shell/rear-panel path; coupon | Diameter-11 continuous swept-probe check plus coupon validity/bbox | Full-cradle handedness corrected; repeat 20 operations, guarding, desk/handled ergonomics, and accidental-actuation test. |
| `MAC-11`, `MAC-12` | Diameter-116 base opening, physically selected diameter-112 cradle opening, 100/112 intake reference | Annular intake exclusion and part-interference checks | Cradle opening reduced 4 mm after physical trial; exact feet/slot contact map and instrumented thermal comparison remain pending. |
| `MAC-13`, `MAC-14` | One top-down HDMI and two inside-mounted USB-C extensions use the accepted V7 geometry. Their Mac-determined paths are preserved and the complete power compartment/C8 island/tunnel is relocated to +X | Hardware references, accepted coupons, blind-axis/support checks, route keep-outs, and removal sweeps | Production geometry transferred; strain support, fully wired cable bends, labels, Mac removal, and functional tests remain pending. |
| `NET-01`, `NET-02` | Official RUTM30 centred `(0,28,170.5)`; revised tray at `Z=151`; four compliant pads; guides shifted inward 1 mm; top ledges lowered 0.6 mm; four Ø6.2 x 2.2 M3x6 recesses; two rigid slotted M3x8 rear corner stops | Official provenance; router/mount, pad/head-clearance, two-stop screw/insert/slot, pairwise, and sampled +Y removal checks; required/connected/build tests | Original loose tray, protruding-head contact, and broken/misplaced flexures are withdrawn. Reprint and verify the revised tray/stops, pad compression, no scratch/rock, screw retention, cables, and service cycles. |
| `NET-03` | One external Ethernet extension at `(X,Z)=(-42,108)` mounts directly in the one-piece rear panel using the accepted horizontal-27 two-hole M3 flange geometry; its measured 42 mm body, 18 mm angled plug, and 20 mm bend remain in the -X low-voltage lane | Connector-count, exact centre, mounting-pattern, validity/build, pairwise, and service-sweep checks | Exact hardware, support/anti-rotation, latch access, bend, and link tests pending. |
| `NET-04`, `NET-05` | The second native router port is allocated to the internal Mac Ethernet link in the low-voltage lane | Modeled packaging keep-outs and topology check; not electrical-separation proof | Actual patch lead, bends, latch access, and link test pending. |
| `NET-06`, `NET-11`, `NET-12` | Six rear bulkhead centres at 20 mm pitch; Ø6.6 holes with 2.0 mm clamping lands; sequence Mobile/Wi-Fi/Mobile/Mobile/Wi-Fi/Mobile | Six-axis hole/land check, connector-count test, router provenance, validity and pairwise checks | Production geometry implemented; actual pigtails, nut torque, strain relief, bends, antenna spacing, and RF/service tests pending. |
| `NET-07`-`NET-09`, `OPEN-02` | Two Type-15 Wi-Fi antennas screw onto the two RP-SMA rear bulkheads; former side docks and shell bosses removed | Registry absence of production docks; six-bulkhead checks and hardware references | Exact gender/pigtails, torque, antenna handling load, spacing, detuning, shake, and 20-cycle tests pending. Legacy dock coupon retained only as revision history. |
| `NET-10` | No PR1KC540 body dock in registry | Code/design inspection | Negative requirement implemented. |
| `NET-12A`, `OPEN-03` | Radius-5 RF opening and `coupon_router_rf_access`; support/liner not frozen | 88 mm span and coupon checks only | Select liner/support; pull/abrasion/bend/service tests with all six actual leads pending. |
| `NET-13`, `MEC-13` | Generic connector/cable/removal solids, low-voltage lane, and stepped reserved Mac-AC corridor | Selected intersections, route continuity, and modeled packaging keep-outs only | Full actual-cable, fully connected unenergized mock-up is a prototype gate; protective power routing remains an electrical-design gate. |
| `NET-14` | Only used RF/Ethernet router functions exposed | Exterior/code review | LEDs/SIM/reset/USB/GNSS openings intentionally absent. |
| `PWR-01`, `PWR-03`, `PWR-07` | `power_compartment.py`: complete box relocated to +X and 3 mm forward; accepted C8 island raised to inlet centre `(38,116)` with two full-depth Ø4.2 M3 insert pockets; two supplier-coordinate APV axes have blind insert pilots accessible from above | APV/box/cover interference; top-service pilot/access/floor witnesses; C8 passage/dual-insert checks, V7 result, validity/build, route, and STEP/STL checks | Mechanical relocation implemented. Exact APV insert/screw/washer stack, C8 insert installation/shroud, terminal routing, and supplier-approved installation pending. |
| `PWR-02`, `PWR-04`-`PWR-06`, `PWR-08`-`PWR-10`, `OPEN-13` | Closed mechanical box/cover, fixed terminal tunnel, two raised sealed-floor tie bridges, four wall-tied upper cover bosses, four open shell-mount bore/head/driver corridors, DC exit, diameter-12 Mac-AC gland, and continuous stepped 6 mm route reservation | Valid/connected/pairwise checks; tie-floor/tunnel, gland, cover-boss, shell-mount-access, route-continuity, and modeled keep-out checks; electrical proof intentionally WARN/PENDING | Mechanical packaging concept only. Mac-AC branch/protection hardware, conduit/barrier, APV lead bends, restraint, competent electrical/material design, and qualified inspection/tests are required before energization. |
| `PWR-11`, `PWR-12` | No external switch or fuse-holder geometry | Design inspection | Implemented; any reviewed fuse remains internal/service-only. |
| `MEC-01`, `MEC-02` | Split body, 18 registered printable definitions (14 installed plus four templates) and 21 coupons; explicit base flip, handed transforms, retainer/coupon transforms, embossed-logo edge print, and per-solid grounding | Part/coupon build checks; `test_all_parts_valid_and_fit_printer`; print-oriented bed-contact test | All bboxes orient within 256 mm computationally. Passed V4 selections are transferred to the production-named parts; historical coupons remain traceability records. |
| `MEC-03` | Removable base/rear/cap, lower/upper shell split, three seam keys, six hidden M4 structural joints, paired internal U-belts, and an angle-reinforced rear sill | Required-part, connected-solid, pairwise, six-axis screw/head/driver/exterior-skin, rear-sill, and rear-removal checks | Mating geometry implemented; M4 coupon, print fit, assembly access, and repeated service pending. |
| `MEC-04` | Paired M3/M4 holes, bosses/rails, and insert coupons; labeled M3x14 base/handle, M3x10 cradle, low-head M3x6 router tray, M3x8 service/cover, M4x10 cap locks, and M4x18 seam stacks | Joint-parameter/engagement, validity/connectivity/pairwise, recess, axis/boss, dovetail, adjustable-stop, and coupon checks | Exact inserts, screw heads/stacks, bottoming, torque/pull-out/access and cycles pending. |
| `MEC-06`, `MEC-11`, `MEC-12` | Material metadata, print plan, palette/renders | No computation proves material/finish | ASA baseline only; owner/process, thermal, and electrical-material review pending. |
| `MEC-07` | One-piece removable rear panel with direct Ethernet/RF mounting and non-encapsulated cable concept; separate bezel deleted | Registry/design inspection | Physical replacement and cable service trial pending. |
| `MEC-08`, `MEC-09` | Power-box raised tie bridges/exits, reserved Mac-AC corridor, low-voltage lane, RF support requirement, clear button/intake paths | Swept button, intake, sealed-floor/tunnel, route, pairwise, and packaging keep-out checks | Final reachable supports, protective power routing/restraint, non-crushing coax dress, and fully wired service trial pending. |
| `MEC-10` | Rear port locations reserved | None appropriate | Discreet durable labels not yet modeled. |
| `SVC-02`, `SVC-04` | Full-height eight-screw one-piece rear panel and +Y corridor; cap/handle and rear antennas remain independent | Sampled panel-plus-connected-hardware +Y sweep and pairwise checks | Fully wired physical removal trial pending. |
| `SVC-03` | Fixed C8 island/tunnel remains with covered compartment while panel removes around it | Pairwise geometry and modeled packaging keep-outs | Mechanical service boundary implemented; qualified touch/probe/electrical review pending. |
| `OPEN-15` | 1.8 kg provisional mass and 4x proof-load factor | Four-screw/boss/bearing load-path geometry only; 70.6 N provisional design target | Weigh complete unit and pass approved controlled proof-load/creep test before carrying. |
| `OPEN-16` | Rear/underside tool-operated fasteners; no lock | Documentation only | Owner tamper/security decision pending. |

## Automated evidence map

| Evidence | Coverage |
| --- | --- |
| `tests/test_parameters.py` | Envelope/ratio, rejection of unsafe partial scaling, distinct joint fits, immutable independent configurations |
| `tests/test_geometry.py` | Required parts/coupons, validity/build, connected installed solids, official router/connectors, collision sensitivity, power ties/APV/cover/gland/route, Mac clip/cam/release, router pad/recess, only-handle allowlist, genuine handle mating, and aggregate zero-FAIL geometry gate |
| `tests/test_exports.py` | STEP/STL round trip, validation gate rejection, non-zero CLI result on failure, actual oriented build-volume bounds, and independent bed contact/manifold checks for every mesh component including multi-body coupons |
| `python -m deployment_station.export` | Every registered STEP reopened, every STL checked, geometry/report/manifest/renders regenerated, failure-gated exit |
| `python -m deployment_station.validation` | Current-source geometry plus existing STL report |

Use the freshly regenerated [validation_results.md](validation_results.md), `validation.json`, and `export_manifest.json` for exact test/validation/artifact counts and hashes. This traceability table intentionally does not preserve pre-regeneration totals. Computational results do not close any physical, thermal, load, signal, cable-routing, or electrical acceptance row.

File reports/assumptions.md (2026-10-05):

# Assumptions, unresolved measurements, and deviations

A named CAD parameter is not automatically a verified physical dimension. This report distinguishes imported authority, controlled placeholders, and unresolved hardware.

## October v4 measured-interface inputs

Owner-supplied measurements and photographs now define a coupon-stage Ethernet adapter (17 x 14 opening, 27.6 mm two-hole pitch, 22 x 23 x 42 mm inner body), HDMI A6-A8T module (16 x 6 opening, 27 mm pitch, 19 x 13 x 13 mm body and 45 mm bend allowance), two USB-C T9B-T8T-NC 20P modules (10 x 4 visible opening, 12 x 5 x 1.75 mm reinforcement shell, 19 mm oval-slot pitch, 14.2 x 2 mm ribbon), and a candidate marketplace C8 inlet (21 x 12.5 opening, 29 mm pitch, 35.5 x 15.1 mm first inner envelope). These are physical prototype inputs, not supplier-controlled drawings.

The supplied Wi-Fi pigtail is RP-SMA female to RP-SMA male with a nominal 6.5 mm bulkhead hole, 8 mm hex, and 2.1 mm inner bearing depth. The four mobile connections still require mechanically checked SMA—not RP-SMA—bulkheads/pigtails. The coupon therefore explores diameter and local panel thickness without treating the two connector families as electrically interchangeable.

The Type-15 Wi-Fi antennas are recorded as 170 mm long and 90-degree adjustable. Their exact hinge/base sweep remains unverified because the marketplace pages could not be accessed by the available browser tools. The DC/DC converter is recorded only as a 71 x 36 x 25 mm, 24 V/1 A envelope; connector positions, retention, heat dissipation, electrical purpose, and suitability remain unresolved.

The approved v4 logo direction retains the existing recessed 70 mm receiver as the sole positional feature and removes the finger scallop. The original shell-magnet/bonded-steel concept passed pocket fit but is superseded for testing by 3 mm shell magnets opposed by 1.5 mm magnets in the removable panel; pull force, polarity, adhesive, and cycles remain pending. The approved cap/handle direction uses underside handle screws and a concealed sliding dovetail connection with a separate positive lock. The physical v2 coupon selected 0.10 mm clearance per side; 0.05 mm was already too tight over the short coupon and is rejected for the full rail. Full-length fit and the final positive lock/load path remain pending.

## Evidence hierarchy

| Item | CAD source | Confidence and boundary |
| --- | --- | --- |
| RUTM30 body | Official Teltonika `reference/0112_RUTM30AMBKX_02.STEP`, AP214, rotated into station axes | **Official imported geometry.** Its station-axis bbox is 100 x 93.7 x 30. Production-unit and connected-hardware checks still apply. |
| RUTM30 connector centres | Official spatial-drawing values encoded analytically | **Controlled reference.** Six RF centres use 14.8 pitch and official ordering; two native Ethernet centres are also represented. Plug/hand/cable envelopes are provisional. |
| Mac mini M4 | 127 x 127 x 50 overall; revised reference separates a 42 mm retained square body from an 8 mm central underside drop | **Physically informed controlled placeholder.** A full-cradle trial selected rear-left button handedness, 0.30 mm side clearance, 8 mm-lower hooks, and a Ø112 opening. No Mac STEP/scan is claimed; exact underside surfaces, contact lands, ports, and overmoulds still require measurement. |
| APV-35-36 | 84 x 57 x 29.5 case plus supplier-drawing lead and lug data | **Controlled placeholder.** Supplied datasheet gives 150 +/-10 mm 18 AWG leads, diameter-3.6 fixing holes, and +/-1 mm case-drawing tolerance. No official APV STEP is claimed. |
| Schurter 6160.0021 | Parametric radiused profile and reference flange from handoff drawing values | **Controlled placeholder.** Actual inlet, current drawing/revision, lifecycle status, mounting method, and terminal envelope are not official imported B-rep data. |
| Two Type-15 Wi-Fi antennas | Owner-specified 170 mm length and 90-degree hinge | **Controlled marketplace input.** Exact hinge/base sweep, gender, mass, RF data, and bending load remain unverified. |
| RF pigtails/bulkheads | Six Ø6.6 rear bulkhead positions; four SMA mobile and two RP-SMA Wi-Fi | **Measured concept input.** Actual pigtail lengths, connector genders, cable construction, bend limit, torque, and support remain unverified. |
| HDMI, dual USB-C, external Ethernet, C8, Mac AC, router DC, and internal power hardware | Accepted V7 mechanical openings/mounts plus simplified cable/service volumes and one stepped Mac-AC reservation | **Physically informed placeholders.** Coupon fit is recorded; functional capability, full tolerance, cable routing, strain relief, and electrical suitability are not established. |

Reference solids are non-printable. Only the RUTM30 is backed by the supplied official STEP; the Mac, APV, antennas, C8, extensions, plugs, and cable paths must not be described as exact models.

## Unresolved measurement and test register

| Gate / ID | Required measurement or decision | Current concept value | Closure evidence |
| --- | --- | --- | --- |
| `OPEN-02` | Two Type-15 Wi-Fi antennas, RP-SMA gender, hinge sweep, spacing, torque, handling load, and RF performance | 170 long; two rear bulkheads in the six-port row | Confirm exact antennas/pigtails, then torque, shake, interference, RF, and 20-cycle tests |
| `OPEN-03` | All six RF bulkheads/pigtails, washer/nut torque, anti-rotation, strain support, first bend, and service | Direct one-piece-panel Ø6.6 holes at 20 pitch; 2.0 mm clamping lands; provisional 20 bend radius | Fully connected rear-panel mock-up and repeated six-port/antenna service test |
| `OPEN-04` | Mac button centre/diameter/travel, feet, intake-slot limits, acceptable support lands, clip/cam contact regions, release access, port centres, and actual overmoulds | Rear-left 13.5 edge offsets; diameter-11 button; Ø112 cradle opening; 0.30 side gap; 42 mm retained-body height; three 2 mm pads in 1 mm seats; four Z-clips and two linked release rails | Reprint corrected cradle, then record contact map, fully cabled fit, 20 button operations, and clip/release/shake cycles |
| APV fit | Production case/lugs, supplier coordinate pattern, lead exits, bend space, case-temperature point, and fasteners | 84 x 57 x 29.5; longitudinal hole-coordinate delta 98.6; two diameter-3.6 top-service axes; 3 mm blind insert pilots; 150 +/-10 leads | Actual part inspection, selected insert/fastener stack, and dry assembly in the closed box |
| `PWR-07` | Exact C8 profile/flange, fixing condition, tolerance, allowed panel thickness, screw access, terminals, and shroud | Accepted 21 x 12.5 +0.40; 30 pitch; two full-depth Ø4.2 M3 heat-set-insert pockets | V7 mechanical pass, production insert trial, and qualified installation/shroud/electrical review |
| Procurement | Availability and lifecycle status of Schurter 6160.0021 | Handoff-specified part; phase-out risk flagged | Supplier confirmation or approved exact substitute followed by geometry and electrical re-review |
| `MEC-13` | Accepted HDMI, dual USB-C, single external Ethernet, internal Mac Ethernet, Mac AC, router DC, coax, grommets, and strain support | V7-derived rear-I/O mounts; one direct rear-panel Ethernet flange; recorded 18 non-coax and 20 coax bend assumptions | Fully wired, unenergized mock-up with accessible releases and no pinching |
| Mac-AC branch | Complete branch topology, junction/protection volume, conduit/barrier, restraint, gland, cable OD, and Mac connector | Diameter-12 floor gland and a continuous stepped 6 mm **reserved envelope** from power box toward the provisional Mac connector | Competent electrical architecture, exact parts, updated CAD, unenergized fit, and qualified inspection/tests before energization |
| Router support | Actual underside safe lands, pad material/compression, fastener-head clearance, and removal force | Four 8 x 16 lands; 1.3 mm pads with 0.4 mm nominal compression; physical 3.0 mm heads over Ø6.2 x 2.2 recesses; guides inset 1.0; rigid slotted rear stops | Reprint; four-pad fit/rock/scratch/thermal check; adjust and cycle both M3x8 stops; repeated -Y insertion/+Y removal |
| Insert release | Chosen M3/M4 insert OD/length/process, pull-out, torque, and parent-material compatibility | physically selected diameter-4.2/5.4 pilots; 5.5 depth | Supplier data and coupon in every final material/orientation |
| `OPEN-15` | Complete assembled mass and approved transport factor | 1.8 kg provisional; 2x test target | Weighed complete prototype and controlled load/time record |
| `OPEN-16` | Tamper/security policy | Rear/underside tool screws; no lock | Owner/service approval |
| `OPEN-18` | Logo appearance, magnet adhesive/polarity/pull force, color/method, rattle, and durability | 70 square; 0.25/side recess clearance; two 6 x 3 plus two 6 x 1.5 magnets per side | Owner approval and at least 20 install/removal cycles |
| Thermal release | Mac/router/APV temperatures and APV derating under representative loads | Passive intake/high exhaust; no fan | Instrumented comparison to agreed open-air baseline |

## Packaging assumptions

- The selected 165 x 165 x 280 package is fixed. `proportionally_scaled()` rejects any other width because equipment and interface datums are absolute.
- The Mac support plane at `Z=24` is 10 above the nominal base top at `Z=14`.
- Router placement at `(0,28,170.5)` prioritizes direct access to the six native RF connectors; its native Ethernet face is consequently opposite the rear service face.
- The APV/mains box is a mechanical containment concept. Its 4 mm keep-out expansion is not a creepage, clearance, insulation, flame, or certification value.
- Cable radii are recorded planning values; the current model uses simplified straight volumes plus a stepped Mac-AC reserved envelope rather than tolerance-complete cables or a released protective conduit.
- The three 2 mm Mac base pads occupy 1 mm-deep seats and avoid the Ø112 underside ring and corrected rear-left button corner. The first full-cradle trial found the original 1.5 mm side gap loose and the hooks 8 mm high; production geometry now uses 0.30 mm clearance and the physically selected lower elevation. Final material, compression, preload, force, contact map, scratch protection, shake behavior, and fatigue remain open.
- The router rests conceptually on four compliant-pad lands clear of modeled vents and the revised deeper M3x6 head recesses. A physical trial found the first tray loose, its 3 mm screw heads contacted the router, and a rear flexure broke 5 mm behind the chassis. Current geometry responds with deeper recesses, inward/lowered guides, and two adjustable screw-mounted rear stops; the revision remains physically unverified.
- The old side Wi-Fi docks are removed. Rear-mounted antennas and their connected pigtails are excluded from the fixed 165 mm body envelope.
- The 116 mm base opening and rear slots are geometric air paths, not airflow or temperature evidence.

## Deviations and implementation choices

| Requirement / target | Decision | Rationale | State |
| --- | --- | --- | --- |
| Direct ports preferred (`MAC-13`, `NET-03`, section 6.1) | HDMI, both USB-C connections, and one external Ethernet use replaceable extensions; the Mac uses the router's other Ethernet port internally | Mac port/plug data are unverified; router Ethernet is opposite the directly exposed RF face | Two router ports now have a resolved one-to-one allocation; exact hardware and functional tests pending |
| Six RF connections (`NET-06`, `NET-12`) | Six panel bulkheads at 20 mm pitch instead of the former common window | Permits standard screw-on external antennas and serviceable short internal pigtails while retaining 2.0 mm clamping lands | Ø6.6/2.0 geometry checked; exact connectors, torque, strain relief, routing, and RF tests pending |
| One external Ethernet plus internal link (`NET-03`, `NET-04`) | One external rear-panel extension and one internal Mac patch lead use the two native router ports | Matches the available two-port router without assuming a switch or third link | Allocation resolved in CAD; actual leads, bends, latch access, and link tests pending |
| Resizing (`ENV-03`) | Non-165 requests are rejected rather than partially scaled | Hardware, ports, splits, clearances, and load paths need coordinated repack, not geometric multiplication | Safer tool behavior; a new size is a new verified configuration |
| Logo retaining concept (`LOGO-06`) | Two concealed magnet pairs per recessed panel; 3 mm shell magnets oppose 1.5 mm panel magnets | Clean exterior with the recess providing position and no doubled 3 mm magnet stack | Pocket/skin/interference checks pass; polarity, adhesive, pull force, cycle/rattle tests pending |
| Handle (`HDL-07`, `HDL-08`) | Continuous Ø22 rounded grip, spherical shoulders, Ø24 round legs, Ø32 flared roots, and radiused 8 mm feet; four underside M3x14 screws; detached cap slides onto two selected dovetails and uses two hidden M4x10 locks | Ergonomic external contact surfaces, clean top face, and a direct load path into shell crossbars; dovetails carry vertical load | Geometry/length/dovetail checks and 4x target pass computationally; insert/material/full-length fit/creep/proof tests pending |
| Routine rear service (`SVC-03`) | Fixed C8 island/tunnel belongs to power box; panel removes around it | Keeps mechanical mains boundary in place during cable service | Geometry implemented; touch-safe/electrical proof pending |
| APV and cover service | Two blind top-service insert pilots and four wall-tied 12 mm upper cover bosses | APV/cover screws are accessible from above after routine shell mounting; the upper bosses do not obstruct the four floor fasteners | Geometry implemented; exact insert, screw, washer, torque, pull-out, material, and electrical acceptance pending |
| Power-cable restraint | Two raised internal bridges replace floor-through tie slots | Preserves a continuous nominal floor beneath the strap tunnels | Geometry implemented; final conductor restraint, abrasion, spacing, and electrical suitability pending |
| Mac-AC routing | Continuous stepped 6 mm reserved envelope from the relocated diameter-12 gland toward the provisional Mac connector | Records a collision-free packaging route without pretending the branch architecture is solved | Geometry-only reservation; conduit/barrier, branch hardware/topology, protection, and qualified proof pending |
| Refined exterior and labels | White/dark palette and restrained openings modeled; final labels absent | Functional packaging precedes graphic/process freeze | Owner appearance and labeling review pending |
| Optional 3MF | STEP and print-oriented STL only | Toolchain does not reliably preserve slicer process settings | 3MF was optional; no functional requirement lost |

No departure from the square 165 x 165 footprint or approximately 1:1:1.70 fixed-envelope ratio has been taken.

## Explicit 230 V review boundary

The CAD creates a closed mechanical box/cover, fixed inlet island/tunnel, raised tie bridges over a nominally sealed floor, top-service APV pilots, wall-tied upper cover bosses, open shell-mount screw corridors, nominal openings, and modeled routing reservations. It does **not** define or validate:

- the complete single-inlet branch topology to the Mac and APV, or the junction/protection volume needed to implement it;
- over-current/branch protection, fuse selection/location, switching, or fault behavior;
- conductors, connectors, terminations, splices, ferrules, insulation, sleeving, or color coding;
- creepage, clearance, protective separation, reinforced/double insulation, fire enclosure, material flammability, or touch-safe probe performance;
- inlet installation/rating, cord anchorage, terminal shrouding, conductor restraint, protective conduit/barriers, strain relief, bushings, or abrasion protection;
- temperature rise, derating, abnormal operation, EMC, dielectric strength, insulation resistance, earth arrangements, or Swiss/EU conformity; or
- an authorized assembly, inspection, test, or service procedure.

The APV datasheet and its component approvals do not certify the integrated station. Before any energization, a competent electrical designer must define the architecture and applicable requirements, and a qualified person must build, inspect, and test the complete unit. Any required fuse remains internal and service-only; no external switch or external fuse holder is modeled.

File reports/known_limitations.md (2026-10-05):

# Known limitations and release blockers

This is editable concept/prototype CAD. It must not be represented as production-ready, safe to carry, or safe to energize.

## Current limitations

1. **The resolved Ethernet allocation still needs physical validation.** One RUTM30 port is reserved for the internal Mac link and the second for the single rear-panel extension; lead routing, latch access, link performance, and service remain unverified.
2. **Connector hardware still needs assembled validation.** The measured Ethernet, HDMI, dual USB-C, and C8 parts fit the accepted V7 coupons and that geometry is transferred into the production rear panel. Cable strain support, exact screws/locking, insertion loads, internal bends, functional performance, and repeated replacement remain unverified; the single RJ45 router extension remains provisional.
3. **The power compartment has been relocated but not physically revalidated.** The complete compartment, raised C8 island/tunnel, APV mounts, cover, and support rails now sit on +X and 3 mm farther forward to preserve the Mac-determined HDMI/USB cable paths. A new print and fully wired clearance/service check are still required.
4. **Only the router has official imported CAD.** `reference/0112_RUTM30AMBKX_02.STEP` is official Teltonika geometry. The Mac, APV, antennas, C8, plugs, extensions, and cables are controlled placeholders.
5. **Physical corrections are not a validated scan.** The full Mac-cradle trial selected rear-left button handedness, 0.30 mm side clearance, an 8 mm lower retained-body/hook datum, and a Ø112 cradle opening. Exact Mac underside surfaces, feet, intake slots, support lands, port centres/overmoulds, antenna bodies, APV production dimensions/lugs/leads, and the inlet still require measured verification.
6. **The specified C8 has procurement risk.** Schurter 6160.0021 availability and phase-out/lifecycle status must be confirmed. Any substitute requires dimensional, mounting, terminal, ratings, and electrical re-review—not a silent part-number swap.
7. **Real cable fit is unknown.** The final plug overmoulds, release tabs, bend limits, service loops, coax liner/support, router DC path, and all simultaneous connections have not been mocked up. The stepped 6 mm Mac-AC solid is only a reserved corridor; it is not a selected protective conduit and does not include branch/protection hardware volume.
8. **RF bulkheads are only geometrically validated.** Six Ø6.6 rear holes retain 2.0 mm clamping lands, but the actual SMA/RP-SMA pigtails, washers/nuts, torque, anti-rotation, strain relief, coax bends, antenna spacing, handling loads, and RF performance are pending.
9. **Printed mechanisms are not durability-qualified.** The original router rear flexure is withdrawn and replaced by two rigid adjustable M3-screwed stops. The former side Wi-Fi docks and router-interface bezel are removed from production. The four Mac clip/cams and release rails, revised router stops, selected cap dovetails, magnetic panels, and inserts still require material-, orientation-, force-, scratch-, conditioning-, carry-, and cycle-specific tests.
10. **Mating supports exist but lack physical proof.** Paired supports are modeled for the cradle, relocated power box, router tray, six-point hidden split-shell seam, sliding cap, underside-mounted handle, magnetic logo panels, and full-height rear panel. Current stack labels are M3x14 base/handle, M3x10 cradle, low-head M3x6 router tray, M3x8 service/cover, M4x10 cap locks, and M4x18 seam; Ø5.4 M4 pilots and 0.10 mm/side dovetails were physically selected, while full-length sliding, bottoming, insert pull-out/torque, revised-print access, wear, and service cycles remain open.
11. **Compliant supports are provisional.** Three 2 mm Mac pads sit in 1 mm seats, and four 1.3 mm router pads sit on printed lands clear of modeled vents and low-head recesses. Actual safe contact regions, material compatibility, compression, rocking, heat, wear, and retention are unverified.
12. **There is no structural rating.** The four-screw handle check verifies geometry and a 4x proof-load target only; it is not FEA or a capacity calculation. Insert pull-out, unequal screw loading, strength, layer adhesion, safe working load, fatigue, creep, impact, and vehicle vibration are untested.
13. **Thermal behavior is unknown.** Passive openings exist, but Mac, router, APV, printed material, pads, cables, and enclosure temperatures; APV derating; throttling; and long-duration/abnormal behavior require component-specific testing.
14. **Electrical construction is unresolved.** Raised tie bridges, blind APV insert pods, upper wall-tied cover bosses, the fixed inlet island, and the closed box are mechanical features—not proof of safe terminals, wiring, branch topology/protection, separation, flammability, touch safety, or compliance.
15. **No ingress or drop rating is intended.** Scope is dry indoor operation and careful hand/vehicle transport only.
16. **Cosmetics and markings are not frozen.** Matte finish, seams, color matching, port/safety labels, logo method, and support-free surface quality need owner and process review.
17. **Non-default scaling is not released.** The API intentionally rejects widths other than 165 because device and hardware interfaces cannot be safely scaled proportionally.
18. **3MF is absent.** STEP and print-oriented STL are authoritative exports; slicer/process settings must be managed separately.
19. **Some parameters remain planning/reserved values.** Cable radii, generic snap allowance, some antenna/handle/logo legacy values, Mac-AC route width, and Wi-Fi mouth-angle target are not all release constraints. Parameter presence is not implementation proof.

## Computational-validation boundary

Use the freshly regenerated [validation_results.md](validation_results.md) and `validation.json` for authoritative counts. This narrative intentionally does not repeat pre-regeneration totals. The automated suite is designed to check:

- square footprint, ratio, and fixed external bbox;
- validity, connected-solid state, and orientable 256 mm bbox for every printable part;
- every pair among the 14 installed printed parts using bounding-box screening and OpenCascade intersection volume, failing closed if an intersection is indeterminate;
- zero unallowlisted installed-part interference; the current screw-mounted design has no intentional overlap allowlist;
- selected equipment-to-shell and equipment-to-mount intersections;
- the Mac intake exclusion and a continuous diameter-11 button-probe swept path through base, cradle, lower shell, and rear panel;
- a continuous reserved Mac-AC packaging corridor and non-overlap of modeled power/low-voltage keep-outs, reported narrowly as packaging evidence rather than electrical-separation proof;
- sealed-floor raised power tie bridges, the full nominal Mac-AC gland aperture, two top-service blind APV pilots, four wall-tied upper cover bosses, and four open shell-mount screw corridors;
- four Mac positive-Z clip/cam interfaces and linked release-rail geometry, plus router support-land/pad, measured screw-head clearance, inward guides, and two rigid adjustable rear-stop joints;
- rear-panel corridor, rear-sill reinforcement, six RF bulkhead holes/lands, magnetic logo pockets/skins, selected cap dovetails/locks, router provenance, six hidden seam corridors, and the four-screw handle insert/bearing/engagement stack;
- STEP reopen during export; and
- STL watertightness and winding consistency.

These computations do **not** prove:

- physical dimensions after FDM shrinkage, warp, aging, or conditioning;
- fit force, rattle, retention, latch access, cable dress, or real removal paths under wiring/gravity;
- absence of every cable/device collision or minimum thickness at every local section;
- mechanical strength, safe load, fatigue, impact, creep, vibration, or accidental release;
- airflow, component temperatures, material temperature/flame behavior, or APV derating;
- HDMI/USB-C/Ethernet function, signal integrity, RF performance/detuning, or EMC; or
- electrical safety, regulatory compliance, or authorization to energize.

A PASS must be read with its exact check description. The Ethernet allocation still needs physical proof; the packaging-only power-route warning and every PENDING physical/safety item remain open.

## Explicit mains/electrical boundary

The fixed C8 island and tunnel remain attached to the covered power compartment when the routine rear panel is removed. Raised tie bridges preserve the nominal floor, top-service APV pilots avoid lower-rail access, and upper wall-tied bosses mate to the cover without blocking the four shell-mount screws. These improve mechanical service geometry but do not validate a 230 V assembly.

The CAD does not specify or approve topology, branch/over-current protection, fuse selection, conductor sizing/type, connectors, splices, terminations, protective conduit/barriers, insulation systems, creepage/clearance, reinforced/double insulation, flammability/fire containment, temperature class, cord/inlet anchorage, shrouding, strain relief, touch safety, dielectric/insulation tests, EMC, or Swiss/EU conformity. The APV and inlet component ratings cannot be transferred to the integrated product.

Before any energization, a competent electrical designer must define the complete architecture and applicable requirements; a qualified person must assemble, inspect, and test the actual unit. Rear service is de-energized. The inner cover is opened only under that approved procedure. Any required fuse is internal/service-only; no external switch or fuse holder is modeled.

## Release gates

Before freezing a complete mechanical prototype:

- close `OPEN-02`, `OPEN-03`, and `OPEN-04` with measured hardware and the exported coupons;
- confirm APV/C8 production geometry and C8 supplier status;
- select and physically retain exact HDMI, USB-C, Ethernet, grommet, liner, and cable hardware, replacing/approving the provisional flange patterns;
- prove the three Mac base pads, four clip/cams, two bottom release rails, four router pads/lands, and low-head tray screws on actual devices;
- complete the Mac-AC branch architecture, reserve all hardware volume, and replace the route envelope with reviewed conduit/barrier/restraint geometry where required;
- complete a fully wired unenergized fit/service mock-up;
- physically validate the resolved one-internal/one-external Ethernet allocation;
- pass insert, panel, button, antenna, RF, logo, tray, cradle, and handle-mount fit/cycle checks; and
- retain zero computational FAIL results after every parameter change/export.

Before carrying or routine energized use:

- weigh the complete assembly and pass approved handle/anchor load, cycle, creep, and accidental-release tests;
- pass representative and abnormal component-specific thermal tests;
- pass service/removal, cable-abrasion/strain, rattle, and transport checks;
- close `OPEN-13`, `OPEN-15`, `OPEN-16`, and `OPEN-18`; and
- complete documented competent electrical review and qualified inspection/tests on the finished hardware.

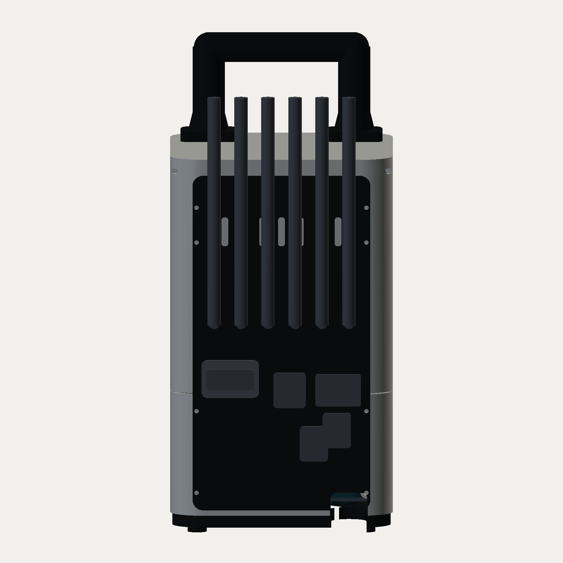
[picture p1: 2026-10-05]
renders/rear_interface.png

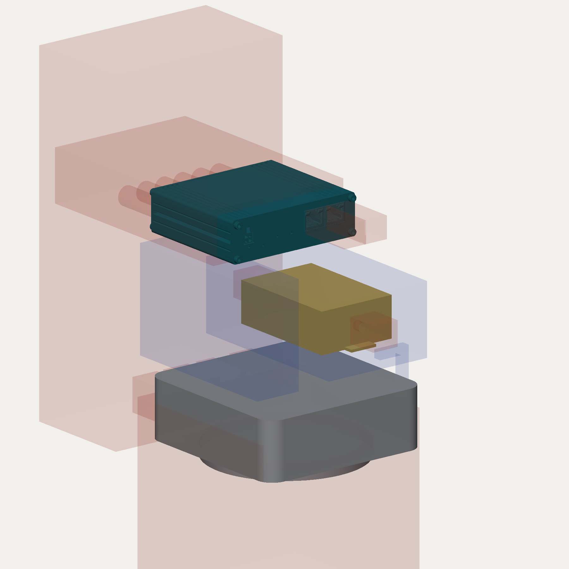
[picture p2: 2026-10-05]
renders/packaging_study.png

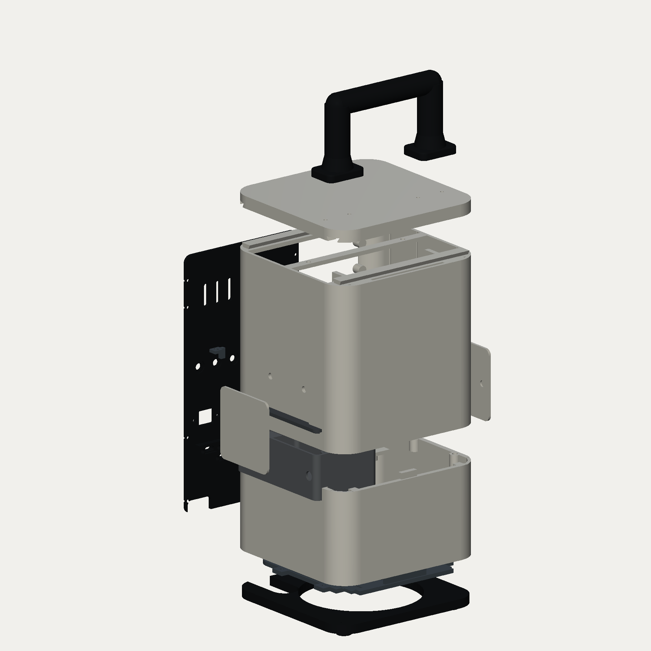
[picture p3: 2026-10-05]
renders/exploded_view.png

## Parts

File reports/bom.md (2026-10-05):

# Bill of materials

This is a prototype-planning BOM, not a purchasing or production release. Quantities describe current CAD positions; screw length/head, insert series, material grade, and all electrical parts remain subject to physical and competent technical review.

## Printed assembly parts

| Part | Qty | Baseline material | Function / boundary |
| --- | ---: | --- | --- |
| `base` | 1 | Dark ASA | Feet, 116 mm intake, continuous button approach, four screw clearances |
| `mac_cradle` | 1 | ASA | Physically calibrated Ø112 opening, 0.30 mm side gap, three 1 mm pad seats, four 8 mm-lowered positive-Z clip/cams, two extended bottom release rails, four shell-fastened ears |
| `lower_shell` | 1 | Matte white ASA | Base/cradle/power supports, rear bosses, angle-reinforced rear sill, three seam keys, internal U-belt, six hidden structural seam inserts |
| `upper_shell` | 1 | Matte white ASA | Router supports, rear bosses, four blind logo-magnet receivers, two cap dovetail rails/crossbars, internal U-belt, six hidden seam lugs/tool corridors |
| `router_tray` | 1 | ASA | Vented plate, four compliant-pad lands, inward-corrected guides, lowered ledges, front stop, two M3 insert towers, and four deeply recessed shell fasteners; brittle rear clips removed |
| `router_rear_retainer_left`, `router_rear_retainer_right` | 1 each | ASA | Rigid slotted rear-corner stops, installed after the router with one M3x8 screw each; remain outside the SMA envelopes |
| `power_compartment` | 1 | Reviewed flame-/temperature-suitable engineering material | Mechanical APV/mains box, fixed C8 island/tunnel, raised sealed-floor tie bridges, two top-service blind APV pilots, four open lower-shell mounting corridors, four upper wall-tied cover bosses, and exits; not an approved electrical enclosure |
| `power_compartment_cover` | 1 | Same reviewed material | Separate deliberate-access cover with four column-aligned M3 clearance axes |
| `rear_panel` | 1 | Dark ASA | Full-height one-piece service face with one Ethernet, relocated HDMI/dual USB-C, six direct Ø6.6 SMA bulkheads with 2.0 mm lands, and fixed C8-island clearance |
| `upper_cap` | 1 | Matte white ASA | Selected 0.10 mm/side dovetail grooves, crossmember, bearing pads, underside handle clearances, and two blind M4 lock inserts |
| `removable_handle` | 1 | Candidate ASA/PA-CF after tests | Continuous cylindrical grip, spherical shoulders, round legs, flared roots, two rounded 42 x 32 x 8 mm feet, and four underside M3 insert pockets; no load rating |
| `logo_panel_left`, `logo_panel_right` | 1 each | ASA or approved variant | Recessed 70 mm faces with two blind 6 x 1.5 mm magnet pockets each |

The registry contains **18 printable definitions**: the 14 installed parts above plus `logo_panel_blank_template`, `logo_panel_example_embossed`, `compliant_pad_template`, and `router_compliant_pad_template`. Make three provisional 14.6 x 14.6 x 2 mm Mac pads for the 1 mm seats and four provisional 8 x 16 x 1.3 mm router pads; material, compression, contact compatibility, and release status remain open.

## Fit coupons

| Coupon | Qty / variants | Purpose |
| --- | ---: | --- |
| `coupon_insert_boss` | Per material/orientation | M3 pilot at nominal diameter and +/-0.2 variants |
| `coupon_m4_seam_insert` | Before either revised shell | Three vertical production-orientation M4 seam pilots: Ø5.4/5.6/5.8, marked by one/two/three edge notches |
| `coupon_c8_cutout` | Per inlet/material candidate | Actual inlet profile, panel, and fixing fit |
| `coupon_rear_panel_fit_v2` | Per shell/panel process | Upright shell receiver plus flat panel insert; X/Z allowances 0.15/0.05 mm per side |
| `coupon_mac_button_recess` | After Mac measurement | Finger reach and guarding |
| `coupon_wifi_dock_v2` | Legacy only | Historical coupon for the removed external Wi-Fi dock; not used by the production V4 enclosure |
| `coupon_router_rf_access` | Legacy only | Historical coupon for the former common RF window; the production V4 uses six individual SMA bulkheads |
| `coupon_logo_mount` | Per panel/shell material pair | Two-screw insert fit, seating, torque, service cycling, and rattle |
| `coupon_handle_mount` | Per structural material/orientation | Representative two-screw foot/pad insert stack; torque, pull-out, and section inspection |

## Owner equipment and controlled components

| Item | Qty | Known nominal data | CAD treatment |
| --- | ---: | --- | --- |
| Apple Mac mini M4 (2024, non-Pro) | 1 | 127 x 127 x 50; about 0.67 kg | Outer dimensions official; cradle datums revised from physical fit, but no validated scan/STEP |
| Teltonika RUTM30 | 1 | 100 x 93.7 x 30; about 0.319 kg | Official AP214 STEP imported from `reference/0112_RUTM30AMBKX_02.STEP` |
| Mean Well APV-35-36 | 1 | 36 V, 1 A, 36 W; 84 x 57 x 29.5; 150 +/-10 mm attached 18 AWG leads | Datasheet-based placeholder; actual fit/temperature/wiring pending |
| Schurter 6160.0021 C8 inlet | 1 | Controlled 28 pitch / diameter-3.2 pattern; exact current drawing governs | Parametric placeholder and coupon; **phase-out/lifecycle and availability risk must be resolved before order** |
| Type-15 Wi-Fi antennas | 2 | 170 mm long, 90-degree hinge, screw-on RP-SMA | Rear bulkhead reference envelopes; no side docks |
| Teltonika PR1KC540 5G combo antenna | 1 | Four cellular leads used; GNSS unused | Four cellular pigtail/bulkhead extensions |

## Data, RF, and cable hardware — exact selection pending

| Item | Provisional qty | Acceptance criteria |
| --- | ---: | --- |
| Panel-supported RJ45 extension/coupler | 1 | Required link category/rate; accepted 17 x 14 opening and 27.6 mm pitch; latch and internal lead access |
| Internal lead for the RJ45 extension | 1 | Correct orientation/performance, 42 mm adapter depth, angled plug, 20 mm bend radius, and service loop |
| Mac-to-router Ethernet patch lead | 1 | Required rate, compact plugs, low-voltage-lane fit; topology warning resolved |
| Panel-supported HDMI extension | 1 | Required HDMI mode end to end, positive mounting, serviceable internal lead; vendor pattern checked against provisional vertical two-hole M3 flange datums |
| Panel-supported USB-C extension | 2 | Explicit data/video/power capability, orientation, positive inside mounting, full-feature test; accepted 19 mm mounting pitch and reinforcement relief |
| SMA/RP-SMA panel bulkheads and short coax pigtails | 6 total | Four cellular plus two Wi-Fi positions; correct gender, Ø6.6 fit, nut torque, bend radius, strain relief, and router-port compatibility |
| Type-15 Wi-Fi antennas | 2 | Screw securely to the two Wi-Fi bulkheads; spacing, hinge clearance, RF performance, handling load, and loosening resistance verified |
| PR1KC540 cellular leads | 4 attached | Connector identity, manufacturer bend limit, and support verified |
| RF bulkhead washers/nuts | 6 sets | Compatible with 2.0 mm printed clamping lands; controlled torque without crushing or rotation |
| Low-voltage cable ties/supports | TBD | Reachable, replaceable, broad/non-crushing for coax |
| DC grommet and Mac-AC gland | 1 each | Exact hardware for diameter-9 and diameter-12 modeled openings after electrical/mechanical review; the stepped 6 mm Mac-AC solid is reserved space, not a selected conduit |

Do not freeze these parts until the actual-cable mock-up and Ethernet-topology decision are complete.

## Mechanical fasteners and inserts

Current joint-stack labels are **M3x14 for the base and underside-mounted handle**, **M3x10 for the Mac cradle**, **low-head M3x6 for the recessed router tray**, **M3x8 for service/cover joints**, **M4x10 for the two hidden cap locks**, and **M4x18 for the shell seam**, with the physically selected diameter-4.2 M3 and diameter-5.4 M4 pilots and 5.5 mm general insert depth. Handle screw heads remain hidden inside the detached cap and engage 5.0 mm into the 8 mm handle feet. These are geometry inputs, not released purchase specifications; verify head form, bottoming, engagement, material, torque, and pull-out physically.

| Joint | Modeled positions | Provisional hardware | Current mating geometry |
| --- | ---: | --- | --- |
| Base to lower shell | 4 M3 | 4 provisional M3x14 screws + 4 M3 inserts | Paired through-holes and webbed shell bosses; longer stack is distinct from service screws |
| Mac cradle to lower shell | 4 M3 | 4 provisional M3x10 screws + 4 M3 inserts | Downward-access holes and shell-tied bosses; nominal stack avoids marginal M3x8 engagement |
| Power compartment to lower shell | 4 M3 | 4 provisional low-head M3x8 screws + 4 M3 inserts | Unchanged lower-shell axes; diameter-3.4 floor bores with verified diameter-6.2 head and diameter-4.5 driver access, two support rails, four shell bosses |
| Power-compartment cover | 4 M3 | 4 provisional M3x8 screws + 4 M3 inserts | Short upper wall-tied bosses and aligned cover clearances; 5.2 mm nominal engagement into 5.5 mm pilots |
| Router tray to upper shell | 4 M3 | 4 M3x6 screws, measured heads no larger than Ø6.2 x 3.0, + 4 M3 inserts | Diameter-6.2 x 2.2 recesses leave 0.8 mm floor and about 0.7 mm nominal router clearance; accessible after +Y router removal |
| Router rear corner stops to tray | 2 M3 | 2 M3x8 screws + washers + 2 M3 inserts | Two top-access adjustable slots into rigid tray towers; replaces broken rear flexures and stays outside SMA envelopes |
| Rear panel to shells | 8 M3 | 8 provisional M3x8 screws + 8 M3 inserts | Counterbores and paired lower/upper rear bosses |
| Logo panels to upper shell | 4 magnet pairs | 4 shell magnets 6 x 3 mm + 4 panel magnets 6 x 1.5 mm + suitable adhesive | Two blind pockets per side; recessed face provides location; polarity and pull-off validation required |
| Removable handle to upper cap | 4 M3 | 4 provisional low-head M3x14 screws + 4 M3 inserts | Screws enter upward from cap underside into two broad 8 mm feet; 5.0 mm nominal engagement |
| Lower-to-upper shell structural seam | 6 M4 | 6 provisional low-head M4x18 screws with measured Ø7.0 heads + 6 M4 inserts | Three per side at X ±76.8 and Y -50/10/50; Ø8.2 internal pockets, 8.4-wide entry slots and top tool corridors, paired U-belts, no exterior openings |
| Upper cap to upper shell | 2 M4 | 2 provisional M4x10 screws + 2 M4 inserts | Selected dual dovetails carry vertical load; two concealed internal locks prevent lateral escape |
| APV fixing | 2 diameter-3.6 axes | Exact screw/insert/washer or approved alternative TBD | Supplier-coordinate axes over 3 mm blind diameter-4.2 pilots with 2.7 mm sealed floor; top service after shell mounting |
| C8 fixing | 2 M3 insert positions | 2 M3 heat-set inserts plus selected screws/locking TBD | Fixed island with full-depth Ø4.2 pockets; terminal access/shroud review required |
| External Ethernet flange | 2 M3 through positions | Vendor-specific screws/nuts/locking TBD | Accepted 27.6 mm pitch with the vertical offset physically corrected |
| Mac HDMI PCB | 2 M3 blind positions | 2 screws + 2 M3 inserts | Accepted top-down mounting on 13 mm shelf, 9 mm axis setback |
| Two Mac USB-C PCBs | 4 M3 blind positions | 4 screws + 4 M3 inserts | Accepted inside mounting on 6 mm bosses with sharp reinforcement pockets |

The modeled printed-part joints total **34 general M3 insert positions** and **8 M4 insert positions**, excluding the two APV axes and connector-specific Ethernet/HDMI/USB hardware; the fixed C8 island adds two dedicated Ø4.2 M3 insert pockets. The six seam screws use physically measured Ø7.0 heads in Ø8.2 x 3.2 pockets and require a long hex driver through the open top. Do not purchase by aggregate count alone: select head type, grade, washer, insert series, length, engagement, torque, access tool, and spare quantity after coupon and joint-stack review.

## Compliant and finishing items

| Item | Provisional qty | Requirement |
| --- | ---: | --- |
| Mac support pads | 3 | Nominal 14.6 x 14.6 x 2 mm TPU/silicone candidate in 1 mm seats; non-marking, replaceable, outside intake/button; compression TBD |
| Mac clip-cam wear pads | 4 | Tiny replaceable candidate pads for the modeled cam pockets; material, adhesion, force, wear, and thickness TBD |
| Router support pads | 4 | Nominal 8 x 16 x 1.3 mm candidate; 0.4 mm compression is provisional; verify safe underside lands, vent clearance, rocking, heat, and retention |
| Non-slip foot pads | 4 if used | Preserve approximately 5 mm loaded air gap; material/adhesive TBD |
| Discreet rear labels | 1 set | LAN/WAN and extended Mac ports; method and durable wording TBD |

## Mains and power-distribution items — competent design required

The following are deliberately **not specified for purchase** while `OPEN-13` remains open:

- single-inlet distribution topology, branch connection/protection hardware, and its required packaging volume;
- Mac and APV mains conductors/connectors/terminations;
- any required internal service-only fuse/protection;
- ferrules, sleeving, barriers, splice enclosure, insulating hardware, and approved electrical fasteners;
- inlet terminal shroud, cord anchorage, glands/grommets, protective conduit/barriers, conductor restraint, strain relief, and required markings; and
- exact flame-/temperature-rated compartment material and process.

A competent electrical designer must select these against the actual voltage, load, fault conditions, temperature, construction, and applicable requirements. APV or inlet component ratings do not qualify the integrated assembly.

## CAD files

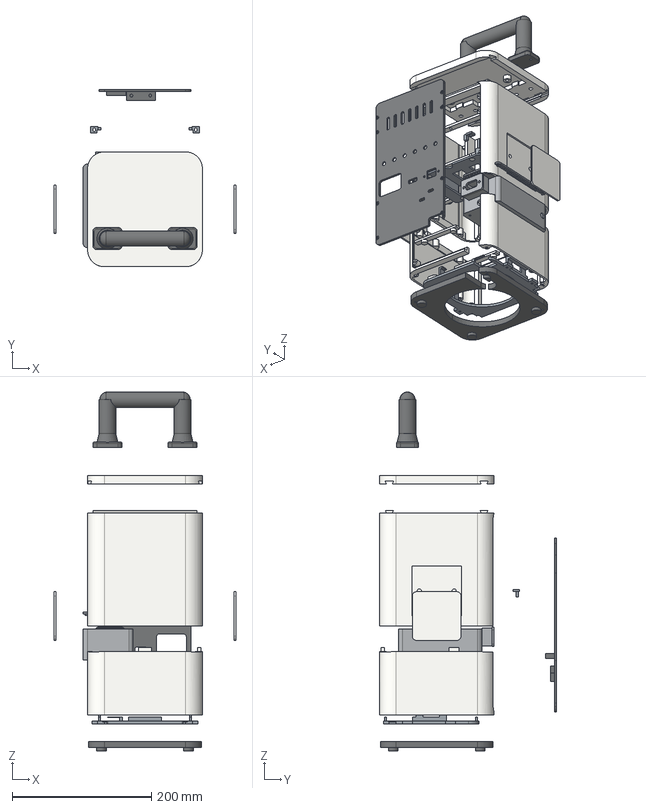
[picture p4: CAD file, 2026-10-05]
exports/step/exploded_assembly.step
261.0 x 255.0 x 516.0 mm
base
mac_cradle
lower_shell
upper_shell
router_tray
router_rear_retainer_left
router_rear_retainer_right
power_compartment
power_compartment_cover
rear_panel
upper_cap
removable_handle
logo_panel_left
logo_panel_right

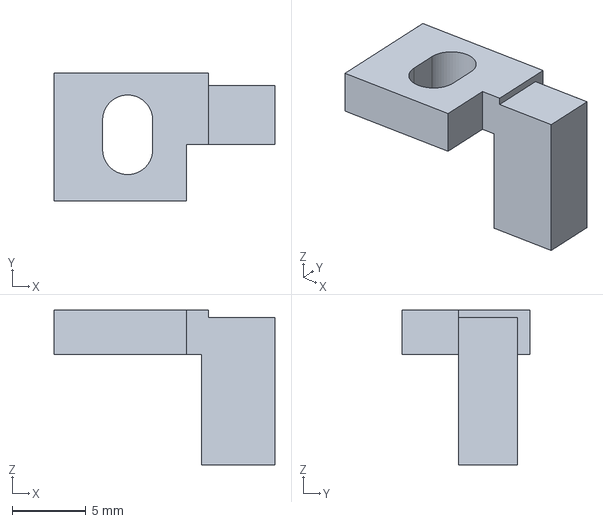
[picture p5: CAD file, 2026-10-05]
exports/step/router_rear_retainer_left.step
15.0 x 8.70 x 10.5 mm

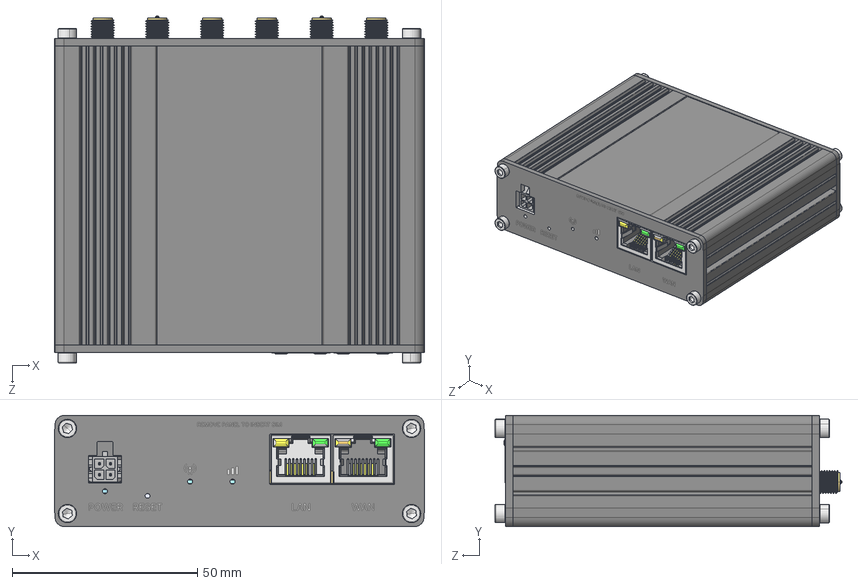
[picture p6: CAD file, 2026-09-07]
reference/0112_RUTM30AMBKX_02.STEP
100.0 x 30.0 x 93.7 mm
0135_RUT301HMBKT_01_RUTM30
0054_RUTM20PRBKT_03_With silkscreen
0238_RUTM20PFBKT_01_With silkscreen
CH-CC-SC-1806214-1_3.03 x 8
0275_RUTM20CX00X_01
0251_RUTM20CX00X_01
0248_RUTM20CX00X_01_padidinta
0252_RUTM20CX00X_01
0277_RUTM30CX00X_01
0259_RUTM30CX00X_01
0260_RUTM30CX00X_01
RUTM30_v2.0_20250110_1055_Simplified

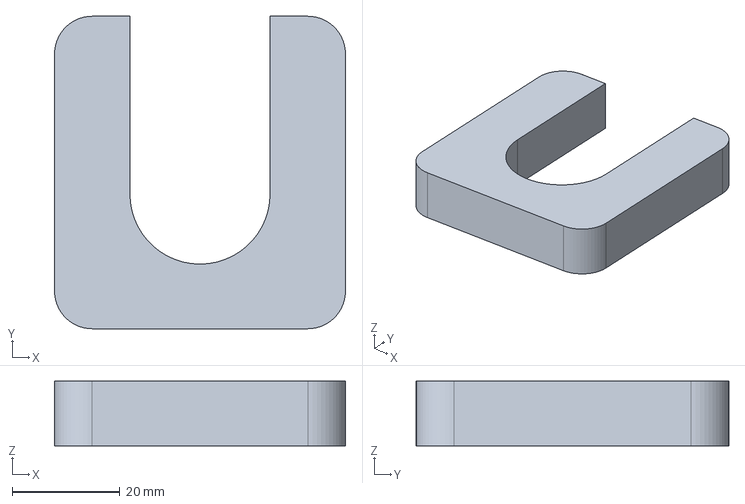
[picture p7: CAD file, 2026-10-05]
exports/step/coupon_mac_button_recess.step
54.0 x 58.0 x 12.0 mm

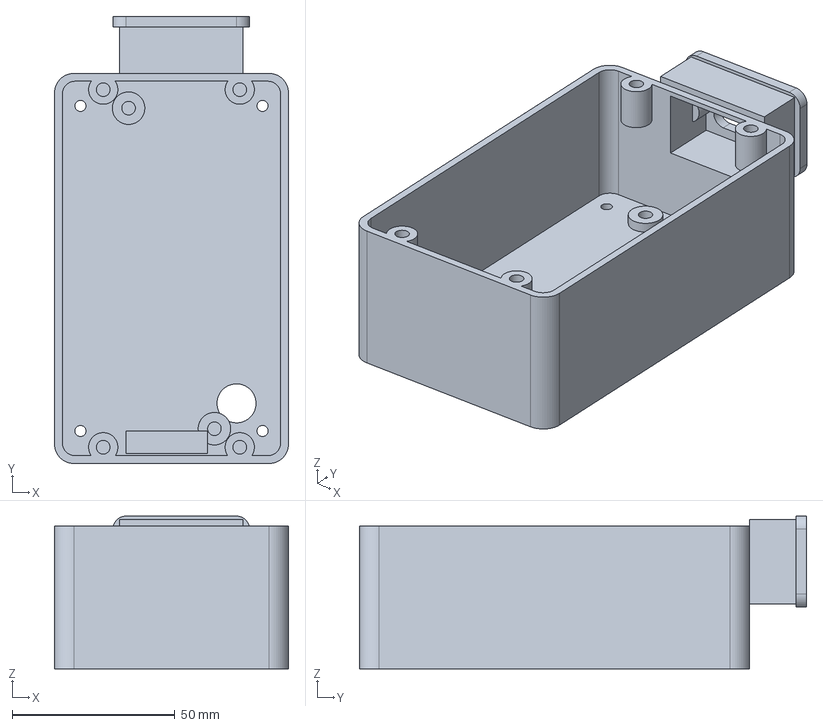
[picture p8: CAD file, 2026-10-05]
exports/step/power_compartment.step
72.0 x 137.5 x 47.0 mm

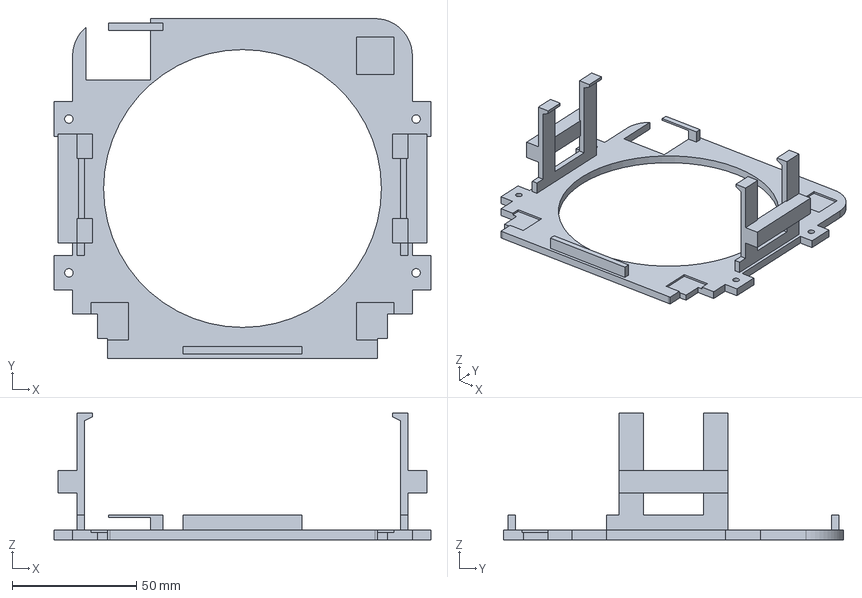
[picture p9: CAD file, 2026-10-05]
exports/step/mac_cradle.step
152.0 x 137.0 x 51.2 mm

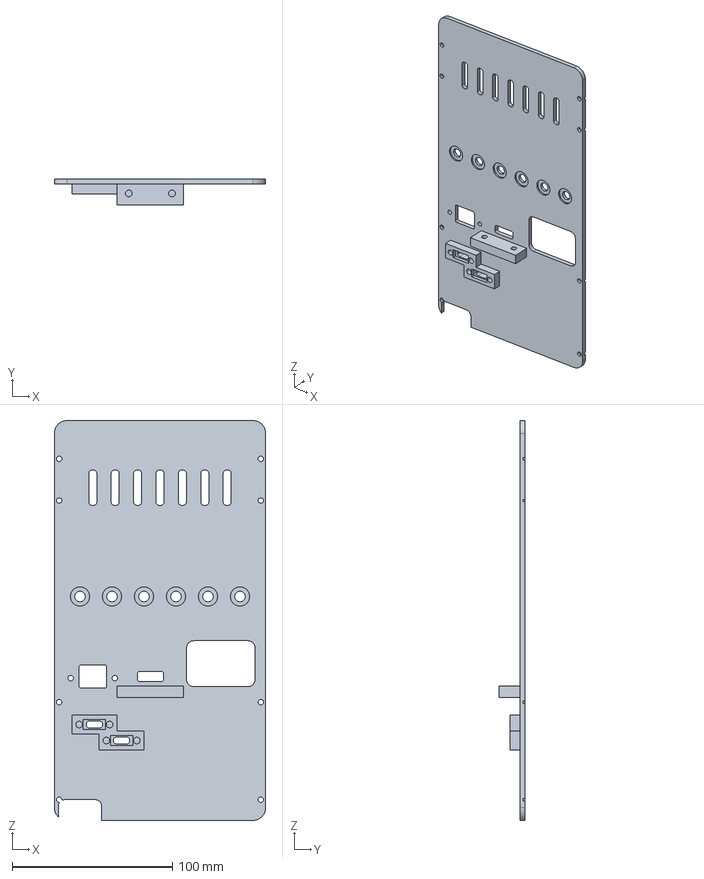
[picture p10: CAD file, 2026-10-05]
exports/step/rear_panel.step
132.0 x 16.2 x 250.0 mm

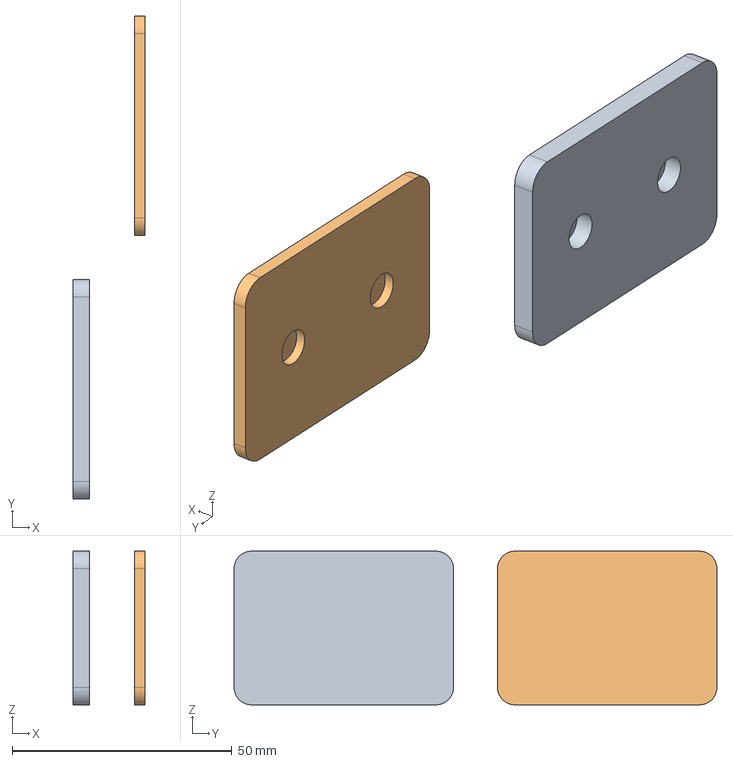
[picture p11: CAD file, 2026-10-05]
exports/step/coupon_logo_magnet_v2.step
16.4 x 110.0 x 35.0 mm

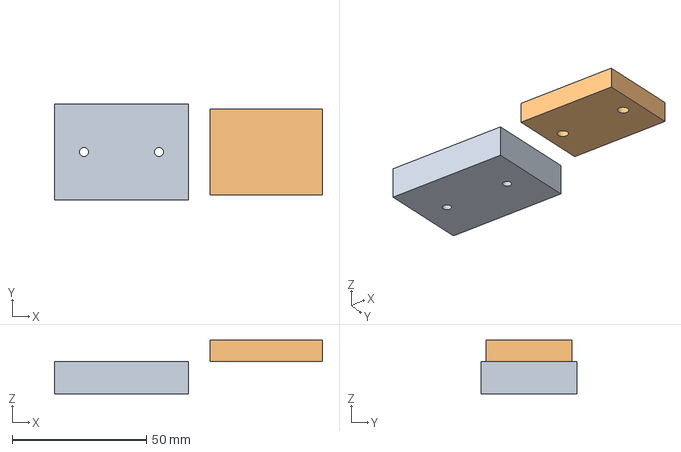
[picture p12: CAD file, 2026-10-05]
exports/step/coupon_handle_mount.step
100.0 x 36.0 x 20.0 mm

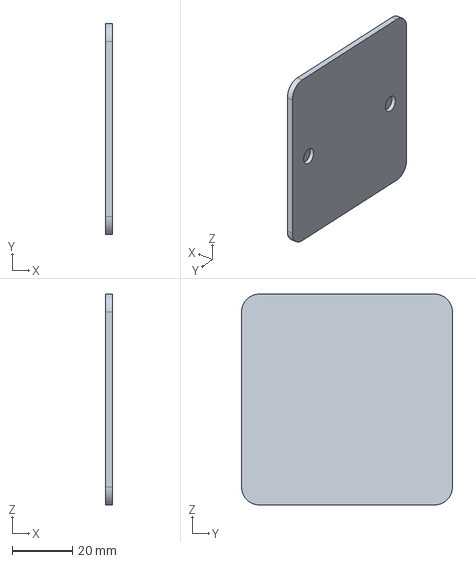
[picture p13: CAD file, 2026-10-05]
exports/step/logo_panel_blank_template.step
2.40 x 70.0 x 70.0 mm

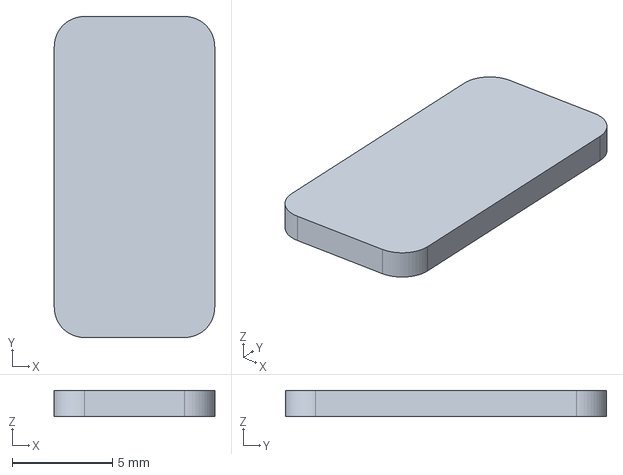
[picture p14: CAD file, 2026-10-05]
exports/step/router_compliant_pad_template.step
8.00 x 16.0 x 1.30 mm

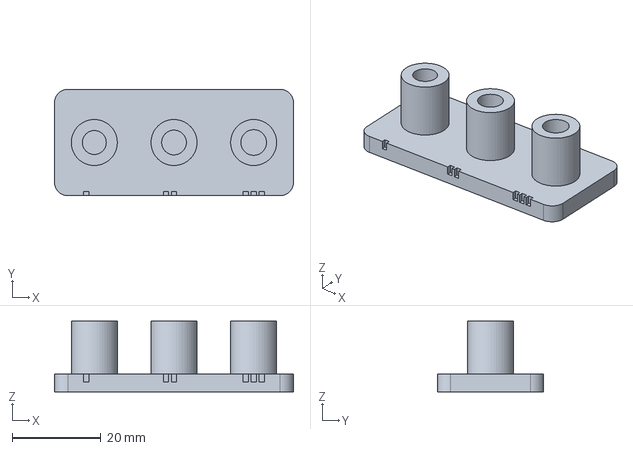
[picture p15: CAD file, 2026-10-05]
exports/step/coupon_m4_seam_insert.step
54.0 x 24.0 x 16.0 mm

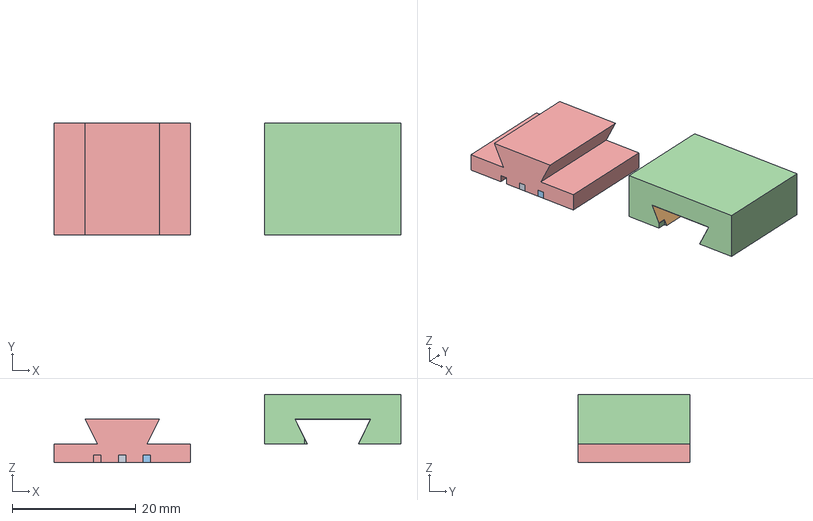
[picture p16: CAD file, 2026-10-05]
exports/step/coupon_cap_dovetail_v2.step
56.0 x 18.0 x 11.0 mm

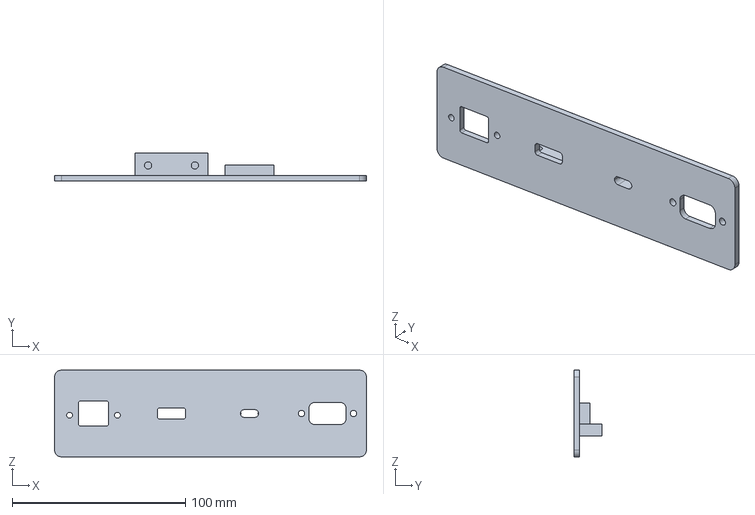
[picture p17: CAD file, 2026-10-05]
exports/step/coupon_rear_io_mount_v7.step
180.0 x 16.2 x 50.0 mm

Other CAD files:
exports/step/coupon_wifi_dock_v2.step
exports/step/logo_panel_right.step
exports/step/compliant_pad_template.step
exports/step/coupon_rear_panel_fit_v2.step
exports/step/base.step
exports/step/coupon_c8_cutout.step
exports/step/coupon_cap_dovetail_v1.step
exports/step/coupon_insert_boss.step
exports/step/coupon_logo_magnet_v1.step
exports/step/coupon_logo_mount.step
exports/step/coupon_rear_io_mount_v2.step
exports/step/coupon_rear_io_mount_v3.step
exports/step/coupon_rear_io_mount_v4.step
exports/step/coupon_rear_io_mount_v5.step
exports/step/coupon_rear_io_mount_v6.step
exports/step/coupon_rear_io_v1.step
exports/step/coupon_rf_bulkhead_v1.step
exports/step/coupon_router_rf_access.step
exports/step/logo_panel_example_embossed.step
exports/step/logo_panel_left.step
exports/step/lower_shell.step
exports/step/power_compartment_cover.step
exports/step/removable_handle.step
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

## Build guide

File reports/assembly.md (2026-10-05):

# Assembly and service sequence

This is a **de-energized mechanical prototype sequence**, not an electrical work instruction. Keep the C8 cord disconnected throughout mechanical assembly and service. Only a competent/qualified person may define and perform mains assembly, inspection, energized tests, or work behind the power-compartment cover.

## Preconditions

1. Print and pass the applicable coupons in [print_plan.md](print_plan.md).
2. Confirm the freshly regenerated [validation_results.md](validation_results.md) has no `FAIL`; review every WARN and PENDING item.
3. Measure the actual Mac, APV, antennas, C8, extensions, inserts, plugs, grommets, liner, and cables. Update parameters/retention geometry and regenerate outputs where results differ.
4. Confirm the intended two-port allocation before wiring: one RUTM30 port serves the internal Mac link and the other serves the single rear-panel Ethernet extension.
5. Have a competent electrical designer define the complete single-inlet topology, protection, materials, separation, shrouding, restraint, labels, inspection, and test plan.
6. Select screw heads/lengths and inserts from coupon and joint-stack results. Verify tool access, engagement, torque, pull-out, perpendicularity, and no boss cracking/breakthrough.

## Mechanical assembly order

1. **Inspect prints.** Deburr only non-calibrated edges. Reject warped interfaces, cracked flexures/bosses, incomplete walls, or damaged cable/connector edges.
2. **Install verified inserts.** Fit the M3 and M4 inserts in their paired shell/compartment bosses using the insert maker's process. The vertical `coupon_m4_seam_insert` trial selected the one-notch Ø5.4 mm pilot. Include the two router-retainer towers, four handle-foot inserts, four upper power-cover bosses, two blind APV pilots, two C8-island inserts in the full-depth Ø4.2 pockets, six seam inserts, and two cap-lock inserts only after the selected insert is proven compatible with its available depth. The logo panels no longer use threaded inserts; install their magnets separately with controlled polarity and suitable adhesive.
3. **Mount the power box mechanically.** Seat revised `power_compartment`, shifted 3 mm forward on the +X side, on the two lower-shell rails and fasten its four unchanged floor positions from inside the completely empty box with provisional low-head M3x8 screws. The corrected model keeps each diameter-3.4 bore, diameter-6.2 head area, and diameter-4.5 driver corridor open; verify all four screws can be started and tightened before fitting the APV or cover. Confirm the raised C8 centre at `(X,Z)=(38,116)` and its fixed island/tunnel align with the rear-panel clearance island, both raised tie bridges are clear, and the nominal diameter-12 Mac-AC gland remains unobstructed.
4. **Dry-fit the unenergized power hardware.** With the compartment already shell-mounted and its cover removed, lower the actual APV onto the two supplier-coordinate axes and install its fixing screws from above into the blind insert/captive concept. Verify the diameter-3.6 lug clearance, washer/head access, insert retention, and no floor breakthrough. Use the raised bridges for a restraint mock-up without drilling the floor. The four wall-tied upper bosses accept a provisional M3x8 cover stack with 5.2 mm nominal engagement. The stepped 6 mm Mac-AC solid is only a reserved routing envelope: branch hardware, conduit/barrier construction, lead bends, topology, and electrical acceptance remain PENDING. Do not wire or energize from this sequence.
5. **Join the body modules.** Before the router tray and cap are installed, place six provisional low-head M4x18 screws into the upper shell's internal lugs. The physically measured Ø7.0 heads move laterally through 8.4 mm internal entry slots and must sit freely within the Ø8.2 x 3.2 pockets. Lower the upper shell onto the three locating keys and the lower shell's six inserts across the 0.8 mm shadow seam. Start and tighten the screws evenly with a long hex driver through the six internal top corridors. The three axes per side are at Y -50/10/50; no screw or opening is exposed on the outside. Confirm all six start freely, the internal U-belts meet without collision, and there is no step, rocking, bottoming, forced fit, or tool contact with other parts.
6. **Install the revised router tray.** Retire the physically loose tray with the broken rear flexure. Fit four tested 8 x 16 x 1.3 mm compliant pads to the printed lands. Fasten the four top-loaded positions into the two upper-shell cross rails using M3x6 screws with measured heads no larger than Ø6.2 x 3.0; the revised Ø6.2 x 2.2 recesses leave about 0.7 mm nominal clearance below the supported router. Install two M3 inserts in the new rear towers. Verify the inward-shifted guides, lowered top ledges, screw heads, lands, and +Y withdrawal corridor are clear.
7. **Install the revised Mac cradle.** Retire the original loose/right-handed print. Fit three approved 2 mm compliant pads into the 1 mm seats of the rear-left/Ø112/0.30-clearance revision; the intended nominal pad top is the Mac support plane, but compression remains a physical test result. Fasten the four cradle ears from below into the lower-shell bosses with provisional M3x10 hardware. Keep the annular intake and button corridor completely clear.
8. **Load and retain the Mac from below.** With the base removed, use the lead-in cams to deflect the four positive-Z clips as the Mac rises horizontally into the cradle. Confirm all four overhangs have their nominal non-contact top gap, the two linked bottom release rails remain reachable, and no printed feature or provisional wear pad marks the Mac, intake, button, finish, or port/plug keep-outs. Fit, force, preload, scratch, shake, and cycle acceptance remain PENDING.
9. **Dry-fit the button and intake.** Temporarily attach the base with the four provisional M3x14 screws. Operate the native button through the continuous lower-rear path and inspect the diameter-116 opening against the physical intake/feet. Remove the base for cable dress.
10. **Install low-voltage/data hardware.** Mount the accepted single Ethernet flange, top-down HDMI PCB, and both USB-C PCBs in the V7-derived rear-panel geometry. Route the Mac Ethernet, HDMI, both USB-C leads, router DC, and the single Ethernet-extension lead in the low-voltage lane with measured service loops and accessible releases. Keep them outside the relocated +X power compartment, mains keep-out, Mac air/button/removal paths, and all fastener tips.
11. **Load and screw-retain the RUTM30.** Leave both rear corner stops off. Present the router at the open rear (+Y) end with its RF row facing rear, then slide it toward the front (-Y) until the fixed front stop is reached. Place `router_rear_retainer_left` and `router_rear_retainer_right` over their towers, move each slotted stop forward until it just meets the outer chassis corner without loading an SMA connector, and secure it from above with one M3x8 screw and washer. Confirm all four pads share support, the router does not rock or scrape, the approximately 0.3 mm physically predicted side clearance remains free, and the native Ethernet face has clear internal lead routing.
12. **Populate the one-piece rear panel.** Dry-fit the selected single RJ45 extension directly in its two-hole M3 flange pattern. Install four cellular SMA and two Wi-Fi RP-SMA bulkheads directly in the six Ø6.6 rear-panel holes, using the 2.0 mm clamping lands and the sequence Mobile / Wi-Fi / Mobile / Mobile / Wi-Fi / Mobile. Torque only to the connector supplier's limit, route the six short coax leads without sharp bends, and add independent strain relief so antenna loads do not reach the router ports. There is no separate router-interface bezel.
13. **Close the rear service face.** Offer the panel over the fixed C8 island without moving the inlet or inner cover. Install the eight provisional M3x8 rear-panel screws. Confirm rear withdrawal needs neither cap/handle nor antenna removal.
14. **Install the magnetic logo panels.** Bond two 6 x 3 mm magnets into each shell receiver and two 6 x 1.5 mm magnets into each panel pocket. Mark and verify polarity before adhesive cure. Seat each panel directly in its existing recess; confirm a flush, non-rattling fit and serviceable pull-off force. No logo screw or finger scallop is used.
15. **Build and attach the cap/handle subassembly.** With the cap detached, install four M3x14 screws upward from its underside into the four inserts in the handle's 8 mm feet. Verify 5.0 mm nominal engagement and full bearing on both cap pads. Slide the complete cap/handle subassembly laterally onto both upper-shell dovetail rails using the physically selected 0.10 mm-per-side fit. From inside the still-open enclosure, install the two concealed M4x10 anti-slide locks. The dovetails carry vertical load; the locks prevent lateral escape. No screw is visible on the top face.
16. **Close the base.** Dress cables clear, then install its four provisional M3x14 screws and verify all feet are stable. The base, cradle, recessed router-tray, and general service stacks deliberately use different lengths.
17. **Proof-check before carrying.** Confirm the cap is fully seated on both dovetails, both hidden M4 locks are installed, all four underside handle screws remain tight, and neither cap nor feet show gaps or cracks. Do not carry equipment until insert pull-out, joint torque, layer adhesion, creep, and controlled proof-load tests pass.

## Intended handle load path

`continuous Ø22 rounded grip -> spherical shoulders -> two Ø24 round legs -> Ø32 flared roots -> two 42 x 32 x 8 mm radiused feet -> four underside M3x14 screws and blind foot inserts -> cap bearing pads/crossmember -> two transverse dovetail rails -> upper-shell crossbars and U-belt -> six hidden M4 shell-seam joints -> lower-shell U-belt, walls, rear-sill angle beam, and equipment supports`

Computational validation checks four clear screw axes, surrounding foot-insert material, broad foot/pad bearing witnesses, both selected dovetails, two hidden M4 cap locks, zero installed interference, and the M3x14/M4x10 length stacks. With the provisional 1.8 kg complete mass, the 4x design proof target is 70.6 N total, or 17.7 N per screw under ideal equal sharing. This is a test target, not an allowable load or capacity claim. It does not perform FEA or establish insert pull-out, material strength, layer adhesion, safe working load, fatigue, impact, creep, or unequal load sharing. Replace the provisional mass with the measured complete mass and proof-test a safely restrained prototype before carrying.

## Routine service sequence

1. Shut down equipment as required; disconnect the external C8 cord, data cables, and antenna connections needed for access; follow the approved electrical procedure; verify de-energization.
2. For cable/interface service, remove the eight rear-panel screws and withdraw the panel along +Y. It moves around the fixed inlet island; leave the separate power cover closed.
3. Replace an extension, patch lead, liner, or low-voltage support without opening the mains compartment. Recheck releases, bends, service loops, and pinch points.
4. For router service, disconnect its RF, Ethernet, and DC connections, remove the two M3x8 rear-stop screws and both corner stops, then withdraw the router along +Y through the rear opening. The four recessed M3x6 tray screws then become accessible if the tray itself must be removed. Reinstallation proceeds from +Y toward -Y; never flex the rigid corner stops around the router.
5. For Mac service, remove the four M3x14 base screws and lower the base. Disconnect the internal Mac leads, use the two bottom-access release rails to deflect the four Z-retention clips outward, and lower the Mac. Release/remove the four cradle screws only if the cradle also needs service. Validate force, hand access, and the fully wired downward-removal sequence on hardware.
6. The Wi-Fi antennas unscrew from their rear RP-SMA bulkheads; the bulkheads remain in the one-piece rear panel unless coax service is required. Pull each magnetic logo panel straight out of its recess with a non-marring suction tab or protected edge tool; neither operation should expose the power cover.
7. Open the power-compartment cover only as a separate deliberate operation by an authorized person under the reviewed electrical procedure.
8. Reassemble in reverse order and inspect every cable, flexure, insert, and joint for wear or damage.

## Physical post-assembly checks

- Stable four-foot support and retained measured air gap.
- Twenty intentional Mac-button operations from desk and handled positions, with no accidental actuation.
- Unobstructed Mac intake/exhaust and instrumented temperature comparison under representative load.
- Fully wired Mac downward removal using both release rails and router removal along +Y without cable/structure interference.
- Four Mac clip/cam engagements, wear pads, two linked release rails, three 2 mm base pads in 1 mm seats, and at least 20 insert/release/shake cycles without damage or unintended release.
- Four router compliant pads share load without rocking, excessive compression, vent obstruction, or screw-head contact; the two rigid adjustable stops retain the rear corners without touching SMA hardware; repeated screw/removal and +Y service cycles remain smooth.
- Full seating, latch/release access, retention, and functional test for HDMI, both USB-C extensions, and the single Ethernet extension.
- Concurrent six-bulkhead RF connection/disconnection with correct nut torque, no rotation, edge abrasion, connector load, or tight coax bend.
- Rear-mounted Wi-Fi antennas withstand handling/shake and at least 20 screw cycles without loosening bulkheads or loading router connectors.
- Logo panels remain flush, non-rattling, and removable after at least 20 cycles.
- Insert/screw joints survive defined torque and repeated service without spin-out or cracked bosses.
- The handle joint survives torque/service cycles, insert pull-out screening, and a safely restrained 4x measured-assembly-weight proof load plus creep dwell before carrying.
- Qualified electrical inspection and applicable tests pass before any routine energized use.

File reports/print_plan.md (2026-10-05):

# Printing plan and coupon order

The baseline target is a Bambu Lab X1 Carbon with a 0.4 mm nozzle. These are prototype starting points, not validated production settings. Confirm the actual printer, plate, filament lot/conditioning, usable build region, slicer, and support/brim allowances.

## Baseline process

| Setting | Starting point | Boundary |
| --- | --- | --- |
| Layer height | 0.20 mm | Tune flexures and calibrated fits from coupons |
| Nominal line width | 0.45 mm | Main wall 3.2; minimum named wall 2.4 |
| Body walls | 7 | About 3.15 nominal; slicer must show continuous roads |
| Body prototype material | ASA | Dry filament and enclosed profile; final grade depends on thermal results |
| Power compartment/cover | Competently reviewed flame-/temperature-suitable grade | Generic ASA or a marketing “FR” label is not automatic electrical approval; avoid PLA |
| Handle/cap | Candidate ASA or PA-CF | Exact material, conditioning, orientation, insert pull-out, creep, and proof-load test govern |
| Supports | Only where preview requires | Keep away from calibrated fit/flexure and visible surfaces where possible |
| Brim/adhesion | Part/process dependent | Shells and large flat parts require warp control |
| Infill | Part specific | Ensure boss/top-skin support; infill percentage does not prove strength |
| Cosmetic seam | Rear or deliberate shadow line | Confirm in slicer and owner review |

Record material manufacturer/grade/color/lot, drying, nozzle, plate, chamber, slicer/profile, orientation, support interface, and post-conditioning for every fit or structural test article.

## Exported STL orientations

STEP remains in assembly coordinates. `export.py` applies these transformations before placing STL geometry on `Z=0`:

| Group | Export transform | Critical slicer review |
| --- | --- | --- |
| Base | Rotate 180 degrees about X, then ground | Broad upper skin on the plate instead of suspending it on four feet; inspect intake/button edges and foot overhangs |
| Cradle, shells, router tray, power box/cover, cap, both pad templates, M3/M4 insert coupons, Mac-button coupon, logo-mount coupon, handle-mount coupon, rear-panel-fit-v2 coupon | Modeled orientation, then ground | Warp/adhesion, tie and retention bridges, boss roads, elephant foot, openings, shell stability, pad thickness, vertical insert axes, and the v2 coupon's upright receiver/flat insert |
| Rear panel, both router rear retainers, C8 coupon, RF-access coupon | Rotate 90 degrees about X | Visible face, connector-edge quality, direct SMA-hole roundness/lands, retainer slots, and support scars |
| Left logo panel | Rotate -90 degrees about Y | Handed face/back orientation, reveal, blind 1.5 mm magnet pockets, and flat seating |
| Right logo panel, blank logo template, legacy Wi-Fi coupon | Rotate +90 degrees about Y | Mirrored panel orientation; the Wi-Fi coupon is retained only as historical calibration evidence |
| Example embossed logo panel | No rotation; edge-print the 70 mm face | Face-down would rest on the emboss; use supports/brim only after preview and cosmetic review |
| Handle | Rotate 90 degrees about X | Cylindrical grip and spherical shoulders, round leg/root layer paths, foot flatness, four screw bores, supports, and surface integrity |

After the listed transform, the exporter repacks disconnected solids along X with a 5 mm gap and independently lowers each one to `Z=0`; this prevents a secondary gauge/key body from floating or fusing into its mate. The actual packed orientation is also checked against the 256 mm build cube. Inspect every body in the slicer anyway. The 250 mm rear panel has limited margin; shells need deliberate brim/support planning. A bounding-box PASS does not include purge towers, brims, printer exclusion zones, or printability of every overhang.

## Recommended coupon order

Do not start either large cosmetic shell until the dependent gates pass.

### V4 prototype-change gate

Before regenerating the large v4 shell/cap/rear-panel parts, print these four small articles from the owner-supplied October measurements:

1. **Rear-I/O gate passed on `coupon_rear_io_mount_v7`.** Ethernet, HDMI, USB-C, and C8 all fit their physical hardware. Freeze the V7 geometry: accepted HDMI height, 13 mm shelf depth and M3 axes; 6.0 mm USB boss bridge with a sharp-cornered 14 x 6.5 x 2.5 mm PCB-facing pocket; and 30.0 mm C8 pitch. No further rear-I/O coupon is required unless the hardware, material, printer, or print settings change. The C8 result is mechanical fit only; it does not authorize wiring or energization.
2. `coupon_rf_bulkhead_v1`: columns left-to-right are diameter 6.6/6.8/7.0 mm; the upper row retains the full 3.2 mm wall and the lower row has a 2.0 mm local land. Select both the smallest smooth hole and the thickest wall that permit full washer/nut thread engagement. Test RP-SMA mechanically for Wi-Fi and the separately sourced SMA mobile bulkhead before freezing a shared geometry.
3. Both Ø6.2 pockets in `coupon_logo_magnet_v2` passed for the Ø6 x 3 mm shell magnet and Ø6 x 1.5 mm logo-panel magnet. Mark polarity before bonding; the magnets must attract. Pull-off force, rattle, adhesive retention, and repeated removal still need to be assessed before applying the arrangement to full panels. The final recessed logo receiver provides position; no extra locating ledge or finger notch is planned.
4. `coupon_cap_dovetail_v1` was too loose at its tightest 0.25 mm pair. On `coupon_cap_dovetail_v2`, the owner selected the two-notch 0.10 mm-per-side pair; the one-notch 0.05 mm pair was already too tight and is rejected for the longer production rail. Apply 0.10 mm per side, then verify the complete cap slides through its full engagement after cooling/conditioning and still uses a separate positive end lock.

All four coupon selections are now recorded and transferred into the production-named parts. The regenerated `upper_shell`, one-piece `rear_panel`, `upper_cap`, ergonomic `removable_handle`, relocated `power_compartment`, `power_compartment_cover`, `lower_shell`, and magnetic logo panels are the current set; do not mix them with earlier printed mating parts. The 71 x 36 x 25 mm DC/DC converter is only a reserved envelope until connector locations, mounting method, heat behavior, and electrical role are supplied. The marketplace C8 coupon is a mechanical fit test only and does not approve the inlet, wiring, insulation, protection, materials, or mains use.

1. **Insert-boss coupon.** Establish M3 pilot in every intended material/orientation; inspect insertion, perpendicularity, torque, pull-out, cracking, and breakthrough.
2. **Hidden-seam M4 insert coupon.** `coupon_m4_seam_insert` was printed in the production orientation; the owner selected the one-notch Ø5.4 mm boss over the Ø5.6 and Ø5.8 alternatives. All M4 insert pilots now use Ø5.4. Repeat only if the insert, material, layer height, wall settings, or conditioning changes; torque/pull-out checks still apply.
3. **C8 cutout coupon.** First reconfirm the specified part's availability/phase-out status and current drawing. Fit the exact inlet and fixing hardware; inspect flange seating, tolerance, panel thickness, rear access, and shroud envelope. This never authorizes wiring or energization.
4. **Rear-panel fit coupon v2.** Print `coupon_rear_panel_fit_v2`: its receiver stands upright like the shell while its separate insert prints flat like the rear panel. Verify the calibrated 0.15 mm/side X and 0.05 mm/side Z nominal allowances, corner seating, insertion, rattle, conditioning change, and repeated removal.
5. **Mac cradle v2 trial.** The original full cradle is withdrawn after physical testing. Print the regenerated `mac_cradle` with its rear-left button path, 0.30 mm side clearance, Ø112 opening, and 8 mm-lowered hooks. Fit three 2 mm base pads into the 1 mm seats plus representative clip-cam wear pads; verify the corrected button corner, full contact map, intake clearance, finish protection, four-cam insertion, both extended bottom releases, shake behavior, and at least 20 cycles.
6. **Legacy Wi-Fi dock coupon v2.** Retain the recorded Ø31.0 result only as revision history. Do not print production docks; the new design uses two screw-on Wi-Fi antennas on rear RP-SMA bulkheads.
7. **RF bulkhead coupon.** The selected production geometry is Ø6.6 with a 2.0 mm thinned clamping land. Reprint `coupon_rf_bulkhead_v1` only if connector hardware, printer, material, or settings change; then confirm washer/nut thread engagement and torque without crushing.
8. **Logo magnet coupon.** The Ø6.2 pockets passed for 6 x 3 mm shell magnets and 6 x 1.5 mm panel magnets. Use `coupon_logo_magnet_v2` for any process change and verify polarity, bonding, pull-off force, rattle, and at least 20 removal cycles.
9. **Revised router tray and stops.** Retire the loose tray with the broken flexure. Print `router_tray`, `router_rear_retainer_left`, and `router_rear_retainer_right`; reuse or print four 8 x 16 x 1.3 pad candidates. Install two Ø4.2-pilot M3 inserts in the rear towers. Verify the four Ø6.2 x 2.2 tray recesses fully contain the selected Ø6.2-or-smaller, 3.0-mm-high M3x6 heads below the router support plane; then check the inward-shifted guides, lowered ledges, common pad loading, no scratch/rock, both M3x8 adjustable stops, and repeated -Y insertion/+Y removal with the stops removed.
10. **Handle-mount coupon.** Test `coupon_handle_mount` with the final cap/handle materials and print settings. Install both foot inserts, use the selected low-head M3x14 screws upward through the cap sample into the 8 mm foot, verify 5.0 mm engagement/no bottoming, then test torque, pull-out, cracking, section quality, conditioning, and service cycling. This coupon is not the complete carrying test.
11. **Structural cap/handle test assembly.** After coupon closure, use all four underside handle M3x14 joints, both selected cap dovetails, both concealed M4x10 locks, all six hidden M4x18 seam joints, shell supports, inserts, and a guarded fixture. Weigh the complete prototype, calculate `4 x measured mass x 9.80665`, then apply only the competently approved proof-load/dwell protocol before any carry trial. Reject permanent deformation, loosened/spun inserts, cracks, layer separation, cap/seam gaps, or measurable creep outside the approved limit.

For this revision, print `lower_shell.stl` and `upper_shell.stl` first to verify the corrected rounded exterior, then `power_compartment.stl` to verify the 3 mm forward shift and both Ø4.2 C8 insert pockets. Print `upper_cap.stl` and `removable_handle.stl` as one mating set, then the one-piece `rear_panel.stl`, followed by both magnetic logo panels. There is no router-bezel part. Dry-assemble the shell seam, cap rails/locks, handle, rear I/O, and all six direct RF bulkheads before installing equipment.

## Part-specific attention

| Part | Review |
| --- | --- |
| Lower/upper shell | Warp, shadow seam, three keys/pockets, rear seat, lower rear-sill angle beam, paired U-belts, six hidden seam bosses/lugs, Ø8.2 head pockets, open driver corridors, relocated +X power rails, magnetic logo receivers, two cap dovetail rails/crossbars, and closed exterior skin |
| Base | Broad skin printed down after 180-degree flip, feet/contact, diameter-116 intake, four M3x14 clearances, continuous button path |
| Mac cradle | Three 1 mm pad seats with 2 mm pads, diameter-112 opening, 0.30 side clearance, four lowered clip/cams and wear pockets, two extended bottom release rails, four ears, rear-left button corridor |
| Router tray and two rear stops | Four compliant lands/pads, inward-shifted guides, lowered top ledges, front stop, vents, four Ø6.2 x 2.2 low-head M3x6 recesses, two webbed Ø4.2 insert towers, two connected slotted M3x8 corner stops, and clear -Y insertion/+Y removal with the stops removed |
| One-piece rear panel | Full 250 mm height, flatness, eight counterbores, +X fixed-island clearance, one Ethernet, user-positioned HDMI/dual USB mounts, six direct Ø6.6 RF holes, and intact 2.0 mm clamping lands |
| Power box/cover | Only reviewed material/process; APV/cable clearance, 3 mm forward position, sealed-floor raised tie bridges, blind top-service APV pilots, four open shell-mount bore/head/driver corridors, four upper wall-tied cover bosses/M3x8 joints, raised C8 tunnel/island with two Ø4.2 insert pockets, gland/exit edges; stepped Mac-AC envelope is not a printable conduit |
| Logo panels | Correct handed transform, matte face, two blind magnet pockets, polarity, reveal, pull-off access, and flat seating; embossed example edge-printed |
| Cap/handle | Continuous perimeter/crossmember, both selected dovetail grooves/rails, two blind M4x10 locks, underside head access, four M3x14 axes, two broad rounded 8 mm feet, insert pockets, cylindrical grip, spherical shoulders, round legs/flared roots, and support removal without damage |

## Print acceptance

A part is eligible for prototype assembly only when:

- the slicer shows intended walls and no omitted thin features;
- no critical face, boss, flexure, rail, hook, or load path is warped, cracked, under-extruded, delaminated, or support-damaged;
- dependent coupons passed in the same material, process, orientation, and conditioning state;
- its current STL mesh check is PASS;
- fit-critical dimensions are measured after cooling/conditioning; and
- structural or electrical suitability has not been inferred from appearance, solid validity, infill, or an “engineering/FR” material name.

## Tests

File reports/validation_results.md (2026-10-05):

# Validation results

Generated by `deployment_station.validation`; dimensions are millimetres.

Summary: 311 PASS, 1 WARN, 12 PENDING, 0 FAIL.

| Check | Status | Detail |
| --- | --- | --- |
| square footprint | PASS | 165.0 x 165.0 mm |
| exterior proportion | PASS | 1 : 1 : 1.6970 (target 1.70) |
| fixed enclosure envelope | PASS | 165.00 x 165.00 x 280.00 mm; antennas and removable handle excluded |
| build volume: base | PASS | bounding box 162.0 x 162.0 x 14.0 mm fits 256 mm cube after orientation |
| valid solid: base | PASS | OpenCascade shape is valid |
| connected printable part: base | PASS | one connected solid |
| build volume: mac_cradle | PASS | bounding box 152.0 x 137.0 x 51.2 mm fits 256 mm cube after orientation |
| valid solid: mac_cradle | PASS | OpenCascade shape is valid |
| connected printable part: mac_cradle | PASS | one connected solid |
| build volume: lower_shell | PASS | bounding box 165.0 x 165.0 x 97.0 mm fits 256 mm cube after orientation |
| valid solid: lower_shell | PASS | OpenCascade shape is valid |
| connected printable part: lower_shell | PASS | one connected solid |
| build volume: upper_shell | PASS | bounding box 165.0 x 165.0 x 166.6 mm fits 256 mm cube after orientation |
| valid solid: upper_shell | PASS | OpenCascade shape is valid |
| connected printable part: upper_shell | PASS | one connected solid |
| build volume: router_tray | PASS | bounding box 120.0 x 98.8 x 37.5 mm fits 256 mm cube after orientation |
| valid solid: router_tray | PASS | OpenCascade shape is valid |
| connected printable part: router_tray | PASS | one connected solid |
| build volume: router_rear_retainer_left | PASS | bounding box 15.0 x 8.7 x 10.5 mm fits 256 mm cube after orientation |
| valid solid: router_rear_retainer_left | PASS | OpenCascade shape is valid |
| connected printable part: router_rear_retainer_left | PASS | one connected solid |
| build volume: router_rear_retainer_right | PASS | bounding box 15.0 x 8.7 x 10.5 mm fits 256 mm cube after orientation |
| valid solid: router_rear_retainer_right | PASS | OpenCascade shape is valid |
| connected printable part: router_rear_retainer_right | PASS | one connected solid |
| build volume: power_compartment | PASS | bounding box 72.0 x 137.5 x 47.0 mm fits 256 mm cube after orientation |
| valid solid: power_compartment | PASS | OpenCascade shape is valid |
| connected printable part: power_compartment | PASS | one connected solid |
| build volume: power_compartment_cover | PASS | bounding box 72.0 x 120.0 x 4.8 mm fits 256 mm cube after orientation |
| valid solid: power_compartment_cover | PASS | OpenCascade shape is valid |
| connected printable part: power_compartment_cover | PASS | one connected solid |
| build volume: rear_panel | PASS | bounding box 132.0 x 16.2 x 250.0 mm fits 256 mm cube after orientation |
| valid solid: rear_panel | PASS | OpenCascade shape is valid |
| connected printable part: rear_panel | PASS | one connected solid |
| build volume: upper_cap | PASS | bounding box 165.0 x 165.0 x 12.0 mm fits 256 mm cube after orientation |
| valid solid: upper_cap | PASS | OpenCascade shape is valid |
| connected printable part: upper_cap | PASS | one connected solid |
| build volume: removable_handle | PASS | bounding box 150.0 x 32.0 x 80.0 mm fits 256 mm cube after orientation |
| valid solid: removable_handle | PASS | OpenCascade shape is valid |
| connected printable part: removable_handle | PASS | one connected solid |
| build volume: logo_panel_left | PASS | bounding box 2.4 x 70.0 x 70.0 mm fits 256 mm cube after orientation |
| valid solid: logo_panel_left | PASS | OpenCascade shape is valid |
| connected printable part: logo_panel_left | PASS | one connected solid |
| build volume: logo_panel_right | PASS | bounding box 2.4 x 70.0 x 70.0 mm fits 256 mm cube after orientation |
| valid solid: logo_panel_right | PASS | OpenCascade shape is valid |
| connected printable part: logo_panel_right | PASS | one connected solid |
| build volume: logo_panel_blank_template | PASS | bounding box 2.4 x 70.0 x 70.0 mm fits 256 mm cube after orientation |
| valid solid: logo_panel_blank_template | PASS | OpenCascade shape is valid |
| build volume: logo_panel_example_embossed | PASS | bounding box 3.2 x 70.0 x 70.0 mm fits 256 mm cube after orientation |
| valid solid: logo_panel_example_embossed | PASS | OpenCascade shape is valid |
| build volume: compliant_pad_template | PASS | bounding box 14.6 x 14.6 x 2.0 mm fits 256 mm cube after orientation |
| valid solid: compliant_pad_template | PASS | OpenCascade shape is valid |
| build volume: router_compliant_pad_template | PASS | bounding box 8.0 x 16.0 x 1.3 mm fits 256 mm cube after orientation |
| valid solid: router_compliant_pad_template | PASS | OpenCascade shape is valid |
| coupon build volume: coupon_c8_cutout | PASS | bounding box 55.0 x 3.2 x 35.0 mm |
| coupon validity: coupon_c8_cutout | PASS | valid shape |
| coupon build volume: coupon_insert_boss | PASS | bounding box 46.0 x 28.0 x 14.0 mm |
| coupon validity: coupon_insert_boss | PASS | valid shape |
| coupon build volume: coupon_m4_seam_insert | PASS | bounding box 54.0 x 24.0 x 16.0 mm |
| coupon validity: coupon_m4_seam_insert | PASS | valid shape |
| coupon build volume: coupon_rear_panel_fit_v2 | PASS | bounding box 120.0 x 22.5 x 37.0 mm |
| coupon validity: coupon_rear_panel_fit_v2 | PASS | valid shape |
| coupon build volume: coupon_logo_mount | PASS | bounding box 23.2 x 32.0 x 18.0 mm |
| coupon validity: coupon_logo_mount | PASS | valid shape |
| coupon build volume: coupon_handle_mount | PASS | bounding box 100.0 x 36.0 x 20.0 mm |
| coupon validity: coupon_handle_mount | PASS | valid shape |
| coupon build volume: coupon_wifi_dock_v2 | PASS | bounding box 17.9 x 120.0 x 42.0 mm |
| coupon validity: coupon_wifi_dock_v2 | PASS | valid shape |
| coupon build volume: coupon_mac_button_recess | PASS | bounding box 54.0 x 58.0 x 12.0 mm |
| coupon validity: coupon_mac_button_recess | PASS | valid shape |
| coupon build volume: coupon_router_rf_access | PASS | bounding box 110.0 x 3.2 x 46.0 mm |
| coupon validity: coupon_router_rf_access | PASS | valid shape |
| coupon build volume: coupon_rear_io_v1 | PASS | bounding box 180.0 x 3.2 x 45.0 mm |
| coupon validity: coupon_rear_io_v1 | PASS | valid shape |
| coupon build volume: coupon_rear_io_mount_v2 | PASS | bounding box 180.0 x 31.2 x 50.0 mm |
| coupon validity: coupon_rear_io_mount_v2 | PASS | valid shape |
| coupon build volume: coupon_rear_io_mount_v3 | PASS | bounding box 180.0 x 31.2 x 50.0 mm |
| coupon validity: coupon_rear_io_mount_v3 | PASS | valid shape |
| coupon build volume: coupon_rear_io_mount_v4 | PASS | bounding box 180.0 x 31.2 x 50.0 mm |
| coupon validity: coupon_rear_io_mount_v4 | PASS | valid shape |
| coupon build volume: coupon_rear_io_mount_v5 | PASS | bounding box 180.0 x 31.2 x 50.0 mm |
| coupon validity: coupon_rear_io_mount_v5 | PASS | valid shape |
| coupon build volume: coupon_rear_io_mount_v6 | PASS | bounding box 180.0 x 16.2 x 50.0 mm |
| coupon validity: coupon_rear_io_mount_v6 | PASS | valid shape |
| coupon build volume: coupon_rear_io_mount_v7 | PASS | bounding box 180.0 x 16.2 x 50.0 mm |
| coupon validity: coupon_rear_io_mount_v7 | PASS | valid shape |
| coupon build volume: coupon_rf_bulkhead_v1 | PASS | bounding box 78.0 x 3.2 x 50.0 mm |
| coupon validity: coupon_rf_bulkhead_v1 | PASS | valid shape |
| coupon build volume: coupon_logo_magnet_v1 | PASS | bounding box 16.4 x 110.0 x 35.0 mm |
| coupon validity: coupon_logo_magnet_v1 | PASS | valid shape |
| coupon build volume: coupon_logo_magnet_v2 | PASS | bounding box 16.4 x 110.0 x 35.0 mm |
| coupon validity: coupon_logo_magnet_v2 | PASS | valid shape |
| coupon build volume: coupon_cap_dovetail_v1 | PASS | bounding box 56.0 x 18.0 x 11.0 mm |
| coupon validity: coupon_cap_dovetail_v1 | PASS | valid shape |
| coupon build volume: coupon_cap_dovetail_v2 | PASS | bounding box 56.0 x 18.0 x 11.0 mm |
| coupon validity: coupon_cap_dovetail_v2 | PASS | valid shape |
| assembly interference: base / mac_cradle | PASS | intersection 0.0000 mm^3 <= 0.10 mm^3 allowance (no intended material overlap) |
| assembly interference: base / lower_shell | PASS | intersection 0.0000 mm^3 <= 0.10 mm^3 allowance (no intended material overlap) |
| assembly interference: base / upper_shell | PASS | intersection 0.0000 mm^3 <= 0.10 mm^3 allowance (no intended material overlap) |
| assembly interference: base / router_tray | PASS | intersection 0.0000 mm^3 <= 0.10 mm^3 allowance (no intended material overlap) |
| assembly interference: base / router_rear_retainer_left | PASS | intersection 0.0000 mm^3 <= 0.10 mm^3 allowance (no intended material overlap) |
| assembly interference: base / router_rear_retainer_right | PASS | intersection 0.0000 mm^3 <= 0.10 mm^3 allowance (no intended material overlap) |
| assembly interference: base / power_compartment | PASS | intersection 0.0000 mm^3 <= 0.10 mm^3 allowance (no intended material overlap) |
| assembly interference: base / power_compartment_cover | PASS | intersection 0.0000 mm^3 <= 0.10 mm^3 allowance (no intended material overlap) |
| assembly interference: base / rear_panel | PASS | intersection 0.0000 mm^3 <= 0.10 mm^3 allowance (no intended material overlap) |
| assembly interference: base / upper_cap | PASS | intersection 0.0000 mm^3 <= 0.10 mm^3 allowance (no intended material overlap) |
| assembly interference: base / removable_handle | PASS | intersection 0.0000 mm^3 <= 0.10 mm^3 allowance (no intended material overlap) |
| assembly interference: base / logo_panel_left | PASS | intersection 0.0000 mm^3 <= 0.10 mm^3 allowance (no intended material overlap) |
| assembly interference: base / logo_panel_right | PASS | intersection 0.0000 mm^3 <= 0.10 mm^3 allowance (no intended material overlap) |
| assembly interference: mac_cradle / lower_shell | PASS | intersection 0.0000 mm^3 <= 0.10 mm^3 allowance (no intended material overlap) |
| assembly interference: mac_cradle / upper_shell | PASS | intersection 0.0000 mm^3 <= 0.10 mm^3 allowance (no intended material overlap) |
| assembly interference: mac_cradle / router_tray | PASS | intersection 0.0000 mm^3 <= 0.10 mm^3 allowance (no intended material overlap) |
| assembly interference: mac_cradle / router_rear_retainer_left | PASS | intersection 0.0000 mm^3 <= 0.10 mm^3 allowance (no intended material overlap) |
| assembly interference: mac_cradle / router_rear_retainer_right | PASS | intersection 0.0000 mm^3 <= 0.10 mm^3 allowance (no intended material overlap) |
| assembly interference: mac_cradle / power_compartment | PASS | intersection 0.0000 mm^3 <= 0.10 mm^3 allowance (no intended material overlap) |
| assembly interference: mac_cradle / power_compartment_cover | PASS | intersection 0.0000 mm^3 <= 0.10 mm^3 allowance (no intended material overlap) |
| assembly interference: mac_cradle / rear_panel | PASS | intersection 0.0000 mm^3 <= 0.10 mm^3 allowance (no intended material overlap) |
| assembly interference: mac_cradle / upper_cap | PASS | intersection 0.0000 mm^3 <= 0.10 mm^3 allowance (no intended material overlap) |
| assembly interference: mac_cradle / removable_handle | PASS | intersection 0.0000 mm^3 <= 0.10 mm^3 allowance (no intended material overlap) |
| assembly interference: mac_cradle / logo_panel_left | PASS | intersection 0.0000 mm^3 <= 0.10 mm^3 allowance (no intended material overlap) |
| assembly interference: mac_cradle / logo_panel_right | PASS | intersection 0.0000 mm^3 <= 0.10 mm^3 allowance (no intended material overlap) |
| assembly interference: lower_shell / upper_shell | PASS | intersection 0.0000 mm^3 <= 0.10 mm^3 allowance (no intended material overlap) |
| assembly interference: lower_shell / router_tray | PASS | intersection 0.0000 mm^3 <= 0.10 mm^3 allowance (no intended material overlap) |
| assembly interference: lower_shell / router_rear_retainer_left | PASS | intersection 0.0000 mm^3 <= 0.10 mm^3 allowance (no intended material overlap) |
| assembly interference: lower_shell / router_rear_retainer_right | PASS | intersection 0.0000 mm^3 <= 0.10 mm^3 allowance (no intended material overlap) |
| assembly interference: lower_shell / power_compartment | PASS | intersection 0.0000 mm^3 <= 0.10 mm^3 allowance (no intended material overlap) |
| assembly interference: lower_shell / power_compartment_cover | PASS | intersection 0.0000 mm^3 <= 0.10 mm^3 allowance (no intended material overlap) |
| assembly interference: lower_shell / rear_panel | PASS | intersection 0.0000 mm^3 <= 0.10 mm^3 allowance (no intended material overlap) |
| assembly interference: lower_shell / upper_cap | PASS | intersection 0.0000 mm^3 <= 0.10 mm^3 allowance (no intended material overlap) |
| assembly interference: lower_shell / removable_handle | PASS | intersection 0.0000 mm^3 <= 0.10 mm^3 allowance (no intended material overlap) |
| assembly interference: lower_shell / logo_panel_left | PASS | intersection 0.0000 mm^3 <= 0.10 mm^3 allowance (no intended material overlap) |
| assembly interference: lower_shell / logo_panel_right | PASS | intersection 0.0000 mm^3 <= 0.10 mm^3 allowance (no intended material overlap) |
| assembly interference: upper_shell / router_tray | PASS | intersection 0.0000 mm^3 <= 0.10 mm^3 allowance (no intended material overlap) |
| assembly interference: upper_shell / router_rear_retainer_left | PASS | intersection 0.0000 mm^3 <= 0.10 mm^3 allowance (no intended material overlap) |
| assembly interference: upper_shell / router_rear_retainer_right | PASS | intersection 0.0000 mm^3 <= 0.10 mm^3 allowance (no intended material overlap) |
| assembly interference: upper_shell / power_compartment | PASS | intersection 0.0000 mm^3 <= 0.10 mm^3 allowance (no intended material overlap) |
| assembly interference: upper_shell / power_compartment_cover | PASS | intersection 0.0000 mm^3 <= 0.10 mm^3 allowance (no intended material overlap) |
| assembly interference: upper_shell / rear_panel | PASS | intersection 0.0000 mm^3 <= 0.10 mm^3 allowance (no intended material overlap) |
| assembly interference: upper_shell / upper_cap | PASS | intersection 0.0000 mm^3 <= 0.10 mm^3 allowance (no intended material overlap) |
| assembly interference: upper_shell / removable_handle | PASS | intersection 0.0000 mm^3 <= 0.10 mm^3 allowance (no intended material overlap) |
| assembly interference: upper_shell / logo_panel_left | PASS | intersection 0.0000 mm^3 <= 0.10 mm^3 allowance (no intended material overlap) |
| assembly interference: upper_shell / logo_panel_right | PASS | intersection 0.0000 mm^3 <= 0.10 mm^3 allowance (no intended material overlap) |
| assembly interference: router_tray / router_rear_retainer_left | PASS | intersection 0.0000 mm^3 <= 0.10 mm^3 allowance (no intended material overlap) |
| assembly interference: router_tray / router_rear_retainer_right | PASS | intersection 0.0000 mm^3 <= 0.10 mm^3 allowance (no intended material overlap) |
| assembly interference: router_tray / power_compartment | PASS | intersection 0.0000 mm^3 <= 0.10 mm^3 allowance (no intended material overlap) |
| assembly interference: router_tray / power_compartment_cover | PASS | intersection 0.0000 mm^3 <= 0.10 mm^3 allowance (no intended material overlap) |
| assembly interference: router_tray / rear_panel | PASS | intersection 0.0000 mm^3 <= 0.10 mm^3 allowance (no intended material overlap) |
| assembly interference: router_tray / upper_cap | PASS | intersection 0.0000 mm^3 <= 0.10 mm^3 allowance (no intended material overlap) |
| assembly interference: router_tray / removable_handle | PASS | intersection 0.0000 mm^3 <= 0.10 mm^3 allowance (no intended material overlap) |
| assembly interference: router_tray / logo_panel_left | PASS | intersection 0.0000 mm^3 <= 0.10 mm^3 allowance (no intended material overlap) |
| assembly interference: router_tray / logo_panel_right | PASS | intersection 0.0000 mm^3 <= 0.10 mm^3 allowance (no intended material overlap) |
| assembly interference: router_rear_retainer_left / router_rear_retainer_right | PASS | intersection 0.0000 mm^3 <= 0.10 mm^3 allowance (no intended material overlap) |
| assembly interference: router_rear_retainer_left / power_compartment | PASS | intersection 0.0000 mm^3 <= 0.10 mm^3 allowance (no intended material overlap) |
| assembly interference: router_rear_retainer_left / power_compartment_cover | PASS | intersection 0.0000 mm^3 <= 0.10 mm^3 allowance (no intended material overlap) |
| assembly interference: router_rear_retainer_left / rear_panel | PASS | intersection 0.0000 mm^3 <= 0.10 mm^3 allowance (no intended material overlap) |
| assembly interference: router_rear_retainer_left / upper_cap | PASS | intersection 0.0000 mm^3 <= 0.10 mm^3 allowance (no intended material overlap) |
| assembly interference: router_rear_retainer_left / removable_handle | PASS | intersection 0.0000 mm^3 <= 0.10 mm^3 allowance (no intended material overlap) |
| assembly interference: router_rear_retainer_left / logo_panel_left | PASS | intersection 0.0000 mm^3 <= 0.10 mm^3 allowance (no intended material overlap) |
| assembly interference: router_rear_retainer_left / logo_panel_right | PASS | intersection 0.0000 mm^3 <= 0.10 mm^3 allowance (no intended material overlap) |
| assembly interference: router_rear_retainer_right / power_compartment | PASS | intersection 0.0000 mm^3 <= 0.10 mm^3 allowance (no intended material overlap) |
| assembly interference: router_rear_retainer_right / power_compartment_cover | PASS | intersection 0.0000 mm^3 <= 0.10 mm^3 allowance (no intended material overlap) |
| assembly interference: router_rear_retainer_right / rear_panel | PASS | intersection 0.0000 mm^3 <= 0.10 mm^3 allowance (no intended material overlap) |
| assembly interference: router_rear_retainer_right / upper_cap | PASS | intersection 0.0000 mm^3 <= 0.10 mm^3 allowance (no intended material overlap) |
| assembly interference: router_rear_retainer_right / removable_handle | PASS | intersection 0.0000 mm^3 <= 0.10 mm^3 allowance (no intended material overlap) |
| assembly interference: router_rear_retainer_right / logo_panel_left | PASS | intersection 0.0000 mm^3 <= 0.10 mm^3 allowance (no intended material overlap) |
| assembly interference: router_rear_retainer_right / logo_panel_right | PASS | intersection 0.0000 mm^3 <= 0.10 mm^3 allowance (no intended material overlap) |
| assembly interference: power_compartment / power_compartment_cover | PASS | intersection 0.0000 mm^3 <= 0.10 mm^3 allowance (no intended material overlap) |
| assembly interference: power_compartment / rear_panel | PASS | intersection 0.0000 mm^3 <= 0.10 mm^3 allowance (no intended material overlap) |
| assembly interference: power_compartment / upper_cap | PASS | intersection 0.0000 mm^3 <= 0.10 mm^3 allowance (no intended material overlap) |
| assembly interference: power_compartment / removable_handle | PASS | intersection 0.0000 mm^3 <= 0.10 mm^3 allowance (no intended material overlap) |
| assembly interference: power_compartment / logo_panel_left | PASS | intersection 0.0000 mm^3 <= 0.10 mm^3 allowance (no intended material overlap) |
| assembly interference: power_compartment / logo_panel_right | PASS | intersection 0.0000 mm^3 <= 0.10 mm^3 allowance (no intended material overlap) |
| assembly interference: power_compartment_cover / rear_panel | PASS | intersection 0.0000 mm^3 <= 0.10 mm^3 allowance (no intended material overlap) |
| assembly interference: power_compartment_cover / upper_cap | PASS | intersection 0.0000 mm^3 <= 0.10 mm^3 allowance (no intended material overlap) |
| assembly interference: power_compartment_cover / removable_handle | PASS | intersection 0.0000 mm^3 <= 0.10 mm^3 allowance (no intended material overlap) |
| assembly interference: power_compartment_cover / logo_panel_left | PASS | intersection 0.0000 mm^3 <= 0.10 mm^3 allowance (no intended material overlap) |
| assembly interference: power_compartment_cover / logo_panel_right | PASS | intersection 0.0000 mm^3 <= 0.10 mm^3 allowance (no intended material overlap) |
| assembly interference: rear_panel / upper_cap | PASS | intersection 0.0000 mm^3 <= 0.10 mm^3 allowance (no intended material overlap) |
| assembly interference: rear_panel / removable_handle | PASS | intersection 0.0000 mm^3 <= 0.10 mm^3 allowance (no intended material overlap) |
| assembly interference: rear_panel / logo_panel_left | PASS | intersection 0.0000 mm^3 <= 0.10 mm^3 allowance (no intended material overlap) |
| assembly interference: rear_panel / logo_panel_right | PASS | intersection 0.0000 mm^3 <= 0.10 mm^3 allowance (no intended material overlap) |
| assembly interference: upper_cap / removable_handle | PASS | intersection 0.0000 mm^3 <= 0.10 mm^3 allowance (no intended material overlap) |
| assembly interference: upper_cap / logo_panel_left | PASS | intersection 0.0000 mm^3 <= 0.10 mm^3 allowance (no intended material overlap) |
| assembly interference: upper_cap / logo_panel_right | PASS | intersection 0.0000 mm^3 <= 0.10 mm^3 allowance (no intended material overlap) |
| assembly interference: removable_handle / logo_panel_left | PASS | intersection 0.0000 mm^3 <= 0.10 mm^3 allowance (no intended material overlap) |
| assembly interference: removable_handle / logo_panel_right | PASS | intersection 0.0000 mm^3 <= 0.10 mm^3 allowance (no intended material overlap) |
| assembly interference: logo_panel_left / logo_panel_right | PASS | intersection 0.0000 mm^3 <= 0.10 mm^3 allowance (no intended material overlap) |
| minimum configured walls | PASS | minimum controlled wall is 2.40 mm |
| equipment vs exterior shell: mac_mini_m4 | PASS | no shell intersection (0.0000 mm^3 numerical residue) |
| equipment vs exterior shell: rutm30 | PASS | no shell intersection (0.0000 mm^3 numerical residue) |
| equipment vs exterior shell: apv_35_36 | PASS | no shell intersection (0.0000 mm^3 numerical residue) |
| equipment/mount interference: mac_mini_m4 / mac_cradle | PASS | intersection 0.0000 mm^3 <= 0.10 mm^3 tolerance |
| equipment/mount interference: rutm30 / router_tray | PASS | intersection 0.0000 mm^3 <= 0.10 mm^3 tolerance |
| equipment/mount interference: apv_35_36 / power_compartment | PASS | intersection 0.0000 mm^3 <= 0.10 mm^3 tolerance |
| equipment/mount interference: apv_35_36 / power_compartment_cover | PASS | intersection 0.0000 mm^3 <= 0.10 mm^3 tolerance |
| Mac positive-Z clip retention | PASS | 4 cantilevers overhang the Mac by 3.0 mm (57.9, 57.9, 57.9, 57.9 mm^3 witnesses); 1.2 mm top gap is clear and installed intersection is 0.0000 mm^3; four underside cam voids and two linked release rails have clear bottom approaches |
| Mac three-pad pocket/support-plane stack | PASS | three 15 mm pockets are 1.0 mm deep with solid floors; 2.0 mm pads finish at Z=24.0 mm |
| RUTM30 four-pad support/counterbore stack | PASS | four 0.6 mm lands plus 1.3 mm pads at 0.4 mm compression finish at router Z=155.5; four 2.2 mm counterbores leave 0.8 mm floor and 0.7 mm below the measured 3.0 mm heads |
| RUTM30 rigid two-screw adjustable rear retention | PASS | two connected corner stops use M3x8 screws, Ø4.2 insert towers, ±1.0 mm slots, a physically corrected rear datum, and 0.5 mm nominal side clearance without entering the official router solid |
| fastener stack: removable base M3x14 | PASS | M3x14: 9.0 mm grip, 5.0 mm pilot penetration, 5.0 mm nominal insert overlap, 6.5 mm tip relief; 4 clear axes with surrounding structural material |
| fastener stack: Mac cradle M3x10 | PASS | M3x10: 4.0 mm grip, 6.0 mm pilot penetration, 5.5 mm nominal insert overlap, 6.5 mm tip relief; 4 clear axes with surrounding structural material |
| fastener stack: router tray M3x6 | PASS | M3x6: 0.8 mm grip, 5.2 mm pilot penetration, 5.2 mm nominal insert overlap, 5.8 mm tip relief; 4 clear axes with surrounding structural material |
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

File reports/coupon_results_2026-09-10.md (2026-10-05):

# Physical coupon observations — 2026-09-10

These are owner-reported prototype observations. Filament grade/lot, drying, slicer profile, orientation confirmation, insert series, screw head/grade, torque, conditioning, cycle count, and photographs were not supplied, so these results guide CAD revision but are not a production release or structural/electrical qualification.

The Mac-cradle follow-up was reported on 2026-09-11.

| Coupon/interface | Reported result | Disposition |
| --- | --- | --- |
| M3 insert boss | Ø4.2 mm selected | Retain the 4.2 mm M3 pilot default; repeat in every final structural material/orientation. |
| M4 seam insert boss | One-notch Ø5.4 mm selected | Set all M4 insert pilots, including the six hidden shell-seam and six cap positions, to Ø5.4 mm. Torque, pull-out, cracking, and final-material confirmation remain required. |
| Handle mount | Pass | Geometry retained. Complete torque, pull-out, 24-hour clamp/creep, full load-path, and 4x measured-weight proof tests remain required. |
| Logo mount | Pass | Geometry retained. Confirm documented torque and 20 service cycles on final material. |
| Rear-panel fit | Original loose; opening measured 42.5 x 22.9 mm, insert measured 41.9 x 22.0 mm. Revised coupon subsequently reported **pass**. | Original coupon withdrawn. Retain separate X/Z allowances of 0.15/0.05 mm per side. `coupon_rear_panel_fit_v2` reproduces upright-shell and flat-panel print orientations. Repeated-removal and conditioned-fit observations remain useful. |
| Wi-Fi dock | Original failed completely on the measured Ø30.0 mm hub. Revised three-marker 31.0 mm capture subsequently reported **pass**. | Original rectangular-lip coupon withdrawn. Production hub cavity set to 31.0 mm with rounded 1.0 mm noses, a 29.5 mm mouth, and 0.25 mm nominal movement per arm. Confirm both antennas plus cable, carry/shake, and 20-cycle behavior. |
| C8 cutout | Pass | Mechanical fit observation only; electrical design, procurement status, shroud, fixing, wiring, inspection, and energized tests remain outside this result. |
| RF access | Pass | Retain geometry; fully dressed cable support, abrasion, bend, and signal tests remain required. |
| Mac button coupon | Pass | The isolated access shape passed, but the subsequent full-cradle trial showed its assembled handedness was wrong; the production path is now mirrored to rear-left. |
| Mac cradle | Fail/revise: button access on wrong side; 1.5 mm measured clip gap is too loose; retaining hooks can be 8 mm lower; central ring/opening is 4 mm too large | Original cradle withdrawn. Mirror the button path to rear-left, use 0.30 mm Mac-specific side clearance, lower hooks by 8 mm, reduce the cradle opening from Ø116 to Ø112, shift the omitted support pad to the corrected button corner, and extend the bottom release rails. Reprint and repeat fit/contact/intake/release/shake/cycle checks. |
| Revised power-compartment lower-shell holes | Pass | Corrected four through-bores/head/tool corridors retained. Cover fit remains a separate check. |
| Original two-point lower/upper shell seam | CAD access fail before print | Withdrawn: upper spines blocked the two screw heads and driver paths. Replaced by six hidden internal M4 joints, paired U-belts, and explicit head/tool/exterior-skin checks. Print the new M4 pilot coupon before either revised shell. |
| Original lower-shell rear sill | Printed part visibly flaps | Withdrawn: the one-sided 4 mm strip is now reinforced by an internal angle beam tied across the lower shell; rear-panel seat and button path remain recut clear. Revised lower shell still requires physical verification. |
| v3 hidden M4 shell screw access | Functional but too tight: measured Ø7.0 mm heads rub the nearby printed shell edge and require force | Existing prints may be used only if undamaged and the heads seat freely after careful internal deburring. Current CAD increases the head pockets from Ø7.6 to Ø8.2 and adds explicit 8.4 mm internal entry slots; no exterior opening is added. |
| First full router tray | Fail/revise: 3.0 mm-high M3 heads protrude and scrape the router; about 1.3 mm side play per side and 1.0 mm top play; one rear flexure broke and sat about 5 mm behind the chassis | Original tray withdrawn. Current tray deepens the head recesses to 2.2 mm, shifts guides inward 1.0 mm, lowers top ledges 0.6 mm, deletes both brittle clips, and adds two rigid slotted M3x8 rear-corner stops. Revised print and no-scratch/fit/service checks pending. |
| V4 measured rear-I/O coupon | **Pass on V7:** all four physical connectors fit: Ethernet, top-down M3 HDMI, inside-mounted USB-C, and C8. The accepted HDMI shelf is 13 mm deep. The accepted USB reinforcement pocket is a sharp-cornered 14 x 6.5 x 2.5 mm rectangle at the PCB/boss plane. | Freeze V7 as the production-interface source and retain v1-v6 as revision records. Transfer V7 into the full rear panel. Move the complete power compartment to +X while preserving the Mac-determined low-voltage paths, then repeat assembled cable/tool/access checks. C8 approval remains mechanical only. |
| V4 RF bulkhead coupon | Pass for the tested part: owner selected variant 1, the one-notch Ø6.6 mm hole, with the lower locally thinned 2.0 mm clamping land. | Use Ø6.6 mm through-holes with a local 2.0 mm land. Test the separately sourced SMA mobile bulkhead as well if the reported part was RP-SMA rather than the final mobile SMA part. |
| V4 logo magnet coupon | Pocket fit pass; the Ø6 mm x 3 mm shell magnets and Ø6 mm x 1.5 mm removable-panel magnets fit their Ø6.2 mm v2 pockets. | Retain the v2 pocket geometry and about 0.7 mm cosmetic panel skin. Mark polarity before bonding; record pull-off feel, rattle, alignment, adhesive retention, and cycles before applying it to full panels. |
| V4 cap dovetail coupon | Pass/select: v1 was loose; on v2 the owner selected the two-notch 0.10 mm-per-side pair. The one-notch 0.05 mm pair is already too tight on the short coupon and would bind more over the full rail length. | Use 0.10 mm clearance per side for the full cap dovetail. Retain a separate positive end lock; fit alone must not be treated as structural handle retention. Verify full-length insertion/removal after printing and conditioning the actual cap/shell materials. |

Use only artifacts regenerated after the two revised coupon results were incorporated. Single-fit coupon closure does not replace the remaining durability, load, cable, thermal, or electrical prototype gates.

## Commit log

2026-09-07 Initial parametric deployment tower design
    [0112_RUTM30AMBKX_02.STEP, base.step, base.stl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]
2026-09-07 Add macOS Finder Quick Look assembly model
2026-09-07 Replace unreachable snap fits with reinforced M3 mounts
    [base.step, compliant_pad_template.step, coupon_c8_cutout.step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]
2026-09-10 Calibrate rear fit and redesign Wi-Fi dock clips
    [base.step, compliant_pad_template.step, coupon_c8_cutout.step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]
2026-09-10 Select 31 mm Wi-Fi dock fit from physical coupon
    [base.step, compliant_pad_template.step, coupon_c8_cutout.step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]
2026-09-11 Calibrate Mac cradle from physical fit
    [base.step, base.stl, compliant_pad_template.step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]
2026-09-12 Fix power compartment mounting access
    [base.step, compliant_pad_template.step, coupon_c8_cutout.step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]
2026-09-12 Add hidden six-point structural shell seam
    [base.step, compliant_pad_template.step, coupon_c8_cutout.step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]
2026-09-12 Apply selected 5.4 mm M4 insert pilot
    [base.step, compliant_pad_template.step, coupon_c8_cutout.step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]
2026-09-14 Increase hidden seam screw head clearance
    [base.step, compliant_pad_template.step, coupon_c8_cutout.step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]
2026-09-14 Replace router clips with screw retainers
    [base.step, compliant_pad_template.step, coupon_c8_cutout.step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]
2026-10-04 Add v4 hardware fit coupons
    [base.step, compliant_pad_template.step, coupon_c8_cutout.step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]
2026-10-04 Separate USB and HDMI mounting concepts
2026-10-04 Add revised rear IO mounting coupon
    [coupon_rear_io_mount_v2.step, coupon_rear_io_mount_v2.stl]
2026-10-04 Revise connector magnets and dovetail coupons
    [coupon_cap_dovetail_v2.step, coupon_cap_dovetail_v2.stl, coupon_logo_magnet_v2.step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]
2026-10-04 Record opposite-side power compartment repack
2026-10-04 Revise rear IO mounting coupon from v3 trial
    [coupon_rear_io_mount_v4.step, coupon_rear_io_mount_v4.stl]
2026-10-04 Move USB reinforcement pocket to boss plane
    [coupon_rear_io_mount_v5.step, coupon_rear_io_mount_v5.stl]
2026-10-04 Select 0.10 mm cap dovetail clearance
2026-10-04 Resize USB pocket and shorten HDMI shelf
    [coupon_rear_io_mount_v6.step, coupon_rear_io_mount_v6.stl]
2026-10-04 Enlarge rear USB pocket with square corners
    [coupon_rear_io_mount_v7.step, coupon_rear_io_mount_v7.stl]
2026-10-05 Implement V4 enclosure and antenna redesign
    [base.step, compliant_pad_template.step, coupon_c8_cutout.step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]
2026-10-05 Refine shell handle and rear interfaces
    [base.step, compliant_pad_template.step, coupon_c8_cutout.step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]
2026-10-05 Correct rear-view connector orientation
    [base.step, compliant_pad_template.step, coupon_c8_cutout.step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]
2026-10-19 Rearrange and label rear antenna ports
2026-10-19 Reduce supports with safer print orientations
2026-10-27 Strengthen leather strap thread profile
2026-10-27 Replace strap fastener with ISO Tr18x4 thread
